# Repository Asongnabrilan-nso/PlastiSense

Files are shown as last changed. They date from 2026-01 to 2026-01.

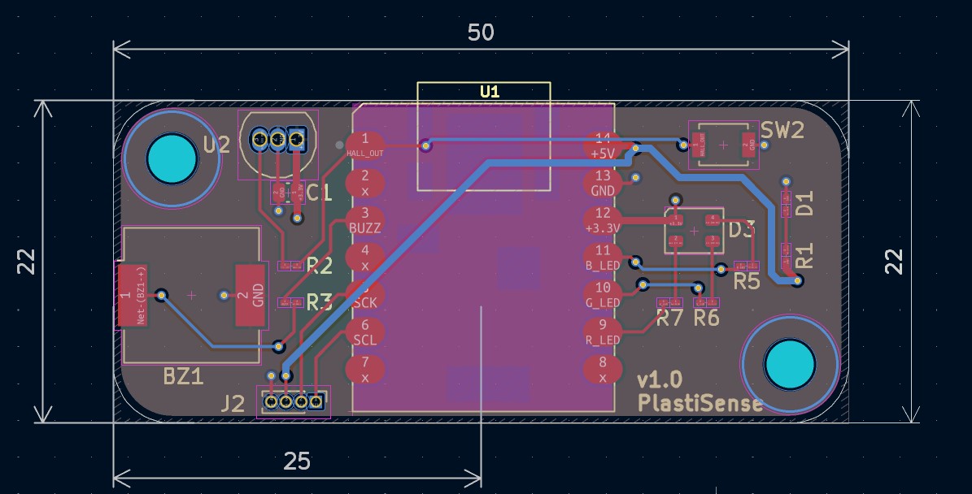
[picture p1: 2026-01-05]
Hardware/PCB Caption.jpg

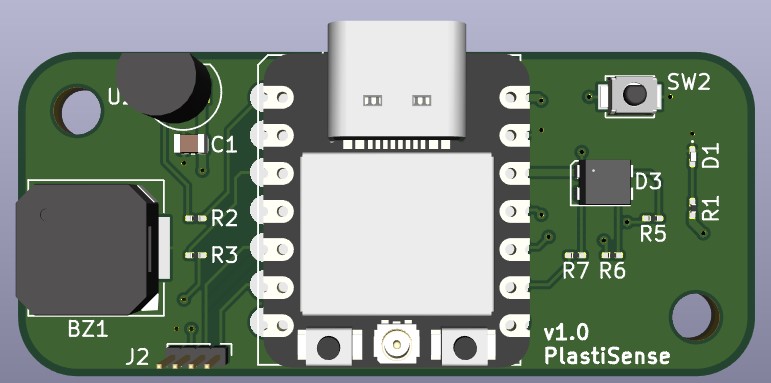
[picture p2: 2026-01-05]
Hardware/PCB-3D.jpg

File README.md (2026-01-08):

[Video: PlastiSense Demo](https://youtu.be/B_dy0DAJdtQ)

# PlastiSense

PlastiSense is a precise **filament diameter sensor** powered by the **Seeed Studio XIAO ESP32-C3**. It is designed to monitor filament quality in real-time, offering a web-based dashboard and API for data integration.

## 🚀 Features

-   **Real-time Measurement**: High-precision diameter readings in millimeters (mm).
-   **Web Dashboard**: Hosted on the device itself (`http://winfidel.local`), providing a visual interface for monitoring.
-   **REST API**: JSON endpoints for easy integration with other systems (e.g., OctoPrint, Home Assistant).
-   **WiFi Connectivity**: Connects to your home/office network.
-   **Captive Portal**: Easy initial setup via the `SK-WInFiDEL-Setup` access point.
-   **OTA Updates**: Support for Over-The-Air firmware updates.

## 🛠️ Hardware

The project is built around:
-   **Microcontroller**: [Seeed Studio XIAO ESP32-C3](https://www.seeedstudio.com/Seeed-XIAO-ESP32C3-p-5431.html)
-   **Custom PCB**: Files located in the `PlastiSense_PCB` dictionary.
-   **Stl Files**: 3D printable case files located in `stl` directory.

## 📁 Project Structure

-   `Firmware/`: Source code for the ESP32-C3 firmware (PlatformIO project).
-   `Hardware/`: Mechanical parts and diagrams.
-   `PlastiSense_PCB/`: KiCad PCB design files.
-   `stl/`: 3D printable STL files for the sensing unit.

## ⚡ Getting Started

### 1. Build & Flush Firmware
Detailed instructions for building and flashing the firmware can be found in the [Firmware Documentation](Firmware/README.md).

### 2. Connect to the Device
1.  Power on the PlastiSense device.
2.  Connect to the WiFi network named **SK-WInFiDEL-Setup**.
3.  A captive portal should open. If not, visit `http://192.168.4.1`.
4.  Configure your local WiFi credentials.

### 3. Access the Dashboard
Once connected to your network, access the device at:
-   **URL**: `http://winfidel.local`
-   **API Endpoint**: `http://winfidel.local/api/v0/diameter/read`

For more details on connection and API usage, see the [Connection Guide](Firmware/connection.md).

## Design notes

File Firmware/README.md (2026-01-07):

# How to build firmware

For our firmware development, we are going to use Arduino. Mainly because it's user friendly, easy to use and
most hobbyists are familiar with it or have already used it. While we could build the same or even more efficient
firmware using bare-metal C and ESP-IDF, we are going to stick with Arduino and hope that this allows the project to be
more friendly and easier to use/modify by wider DIY/hacker community.

## How can I build/compile firmware?

### 1. Install PlatformIO
Installing PlatformIO CLI is pretty straight-forward and also well documented for Windows, Linux and MacOS.
You will need to follow few steps and get PlatformIO CLI installed, detailed tutorial can be found at https://platformio.org/install/cli
Make sure to install [PlatformIO Core](https://docs.platformio.org/en/latest//core/installation.html#installation-methods 'https://docs.platformio.org/en/latest//core/installation.html#installation-methods') and allso that it is available trough [shell](https://docs.platformio.org/en/latest//core/installation.html#piocore-install-shell-commands 'PlatformIO Core - Install Shell Commands¶').

### 2. Build firmware
Open shell/command-prompt and navigate to 'Firmware/platformio' folder.

1. Compile and upload the firmware with `pio run --target upload --upload-port <COM-PORT>`. Make sure to replace `<COM-PORT>` with your ESP32's COM port (ie COM1 or /dev/ttyACM0)
2. Upload the file system (Web page) with `pio run --target uploadfs --upload-port <COM-PORT>`, again replace `<COM-PORT>` with your ESP32's COM port.
3. Restart/power-cycle your board

Every time you make a firmware change, you need to run step #1.
Every time you make a change to the web page (anything inside `data` folder) you only need to run step #2.

[<- Go back to repository root](../README.md)

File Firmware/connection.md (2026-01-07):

Connecting to WInFiDEL ("Log In" Process)
There is no traditional "Log In" screen for the web interface itself. The security is handled by the WiFi connection.

Step 1: Initial Setup (The "Login")
When the device is fresh or reset, it creates its own WiFi network. This is where you "log in" by providing your home WiFi credentials.

Power on your XIAO ESP32-C3 device.
On your phone or computer, look for a WiFi network named SK-WInFiDEL-Setup.
Connect to this network.
A page should pop up automatically ("Captive Portal").
If it doesn't pop up, open a browser and go to http://192.168.4.1
Click Configure WiFi.
Select your home/office WiFi network.
Enter your WiFi Password.
Click Save.
The device will now save these credentials, disconnect from your phone, and connect to your home network.

Step 2: Accessing the Interface
Once the device is connected to your home network, anyone on that network can access it.

Connect your phone/computer back to your Home WiFi.
Open a browser and go to:
http://winfidel.local
Note: If winfidel.local doesn't work (common on some Windows setups or Androids), you will need the device's IP address. You can find this in your router's device list, or by monitoring the Serial output (USB) when the device boots.
Step 3: Using the API
The API is open to anyone on the network. You do not need a username or password.

View Dashboard: http://winfidel.local/index.html
Settings: http://winfidel.local/settings.html
Raw Data (API): http://winfidel.local/api/v0/diameter/read
NOTE

If you messed up the WiFi password in Step 1, you can reset the settings via the Serial Monitor or by reflashing the device, and start over from Step 1.

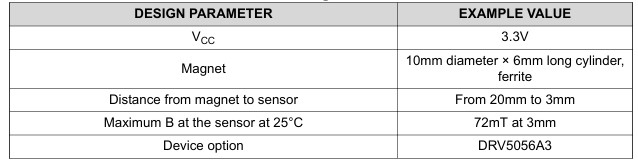
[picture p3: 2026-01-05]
assets/design parameter.jpg

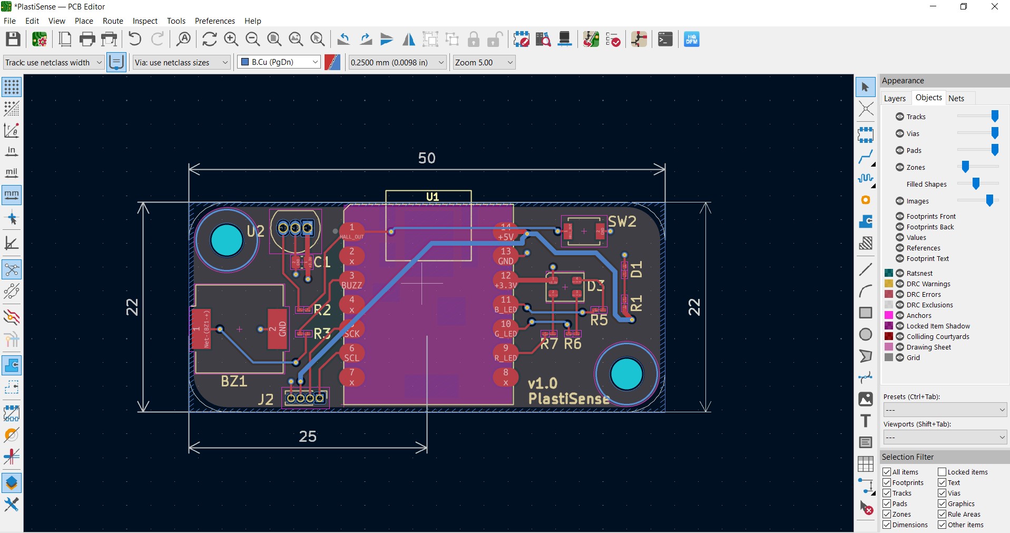
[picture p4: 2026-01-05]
Hardware/PCB-image.jpg

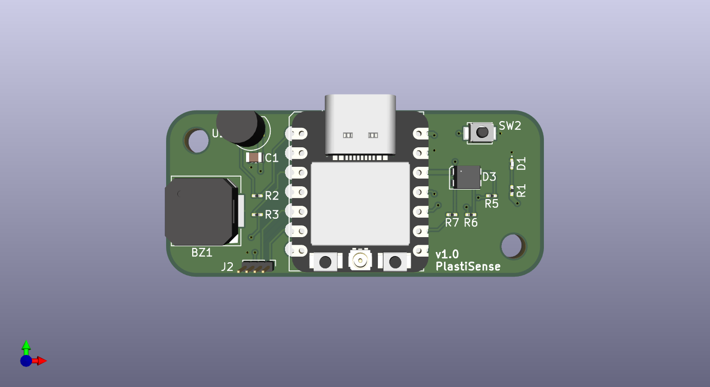
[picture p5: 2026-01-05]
Hardware/PlastiSense.png

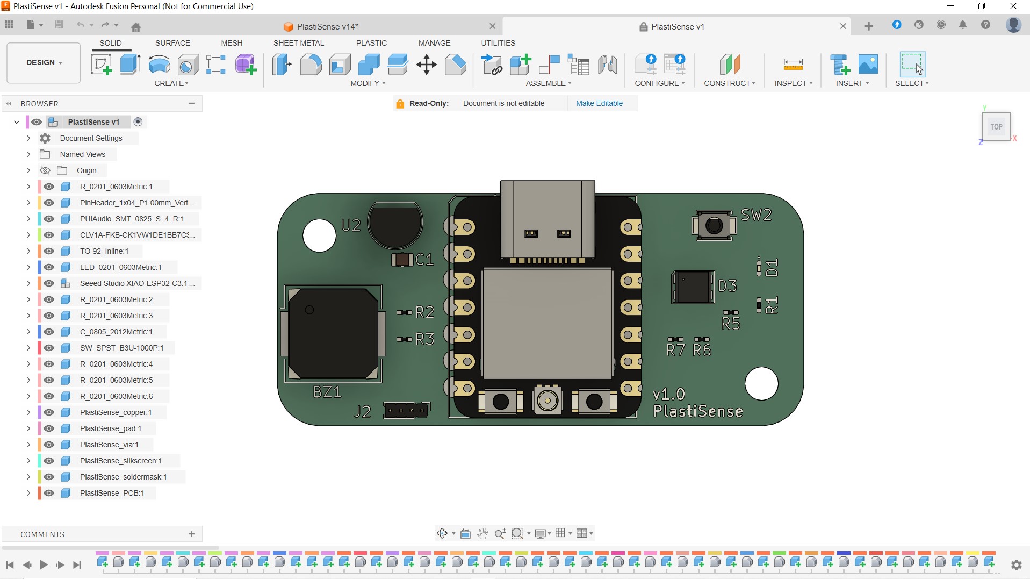
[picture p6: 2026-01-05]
Hardware/PCB-Fusion.jpg

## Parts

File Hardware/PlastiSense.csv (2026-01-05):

Reference | Qty | Value | DNP | Exclude from BOM | Exclude from Board | Footprint
BZ1 | 1 | Buzzer |  |  |  | Buzzer_Beeper:Buzzer_CUI_CPT-9019S-SMT
C1 | 1 | 0.1uF |  |  |  | Capacitor_SMD:C_0504_1310Metric_Pad0.83x1.28mm_HandSolder
D1 | 1 | GREEN |  |  |  | LED_SMD:LED_0201_0603Metric_Pad0.64x0.40mm_HandSolder
D3 | 1 | CLV1L-FKB |  |  |  | LED_SMD:LED_Cree-PLCC4_3.2x2.8mm_CCW
H1,H2 | 2 | MountingHole |  | Excluded from BOM |  | MountingHole:MountingHole_3.2mm_M3
J2 | 1 | Conn_01x04 |  |  |  | Connector_PinHeader_1.00mm:PinHeader_1x04_P1.00mm_Vertical
R1,R3 | 2 | 1k |  |  |  | Resistor_SMD:R_0201_0603Metric_Pad0.64x0.40mm_HandSolder
R2 | 1 | 4K7 |  |  |  | Resistor_SMD:R_0201_0603Metric_Pad0.64x0.40mm_HandSolder
R5,R6,R7 | 3 | 220 |  |  |  | Resistor_SMD:R_0201_0603Metric_Pad0.64x0.40mm_HandSolder
SW2 | 1 | SW_Push |  |  |  | Button_Switch_SMD:SW_SPST_B3U-1000P
U1 | 1 | MOUDLE-SEEEDUINO-XIAO-ESP32C3 |  |  |  | xiao ESP32C3_PCB:MOUDLE14P-SMD-2.54-21X17.8MM
U2 | 1 | HALL SENSOR |  |  |  | Package_TO_SOT_THT:TO-92_Inline

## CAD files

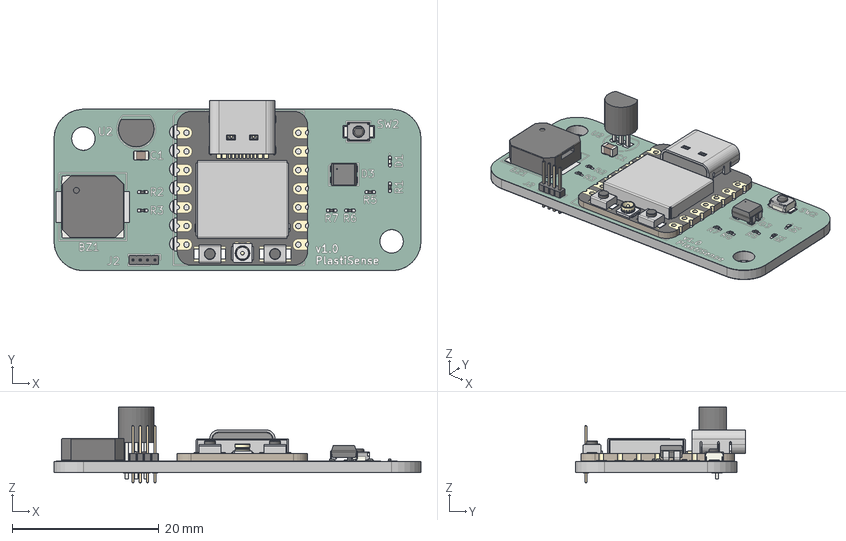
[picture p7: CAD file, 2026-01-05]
Hardware/PlastiSense.step
50.0 x 23.2 x 10.3 mm
R_0201_0603Metric x 6
PinHeader_1x04_P1.00mm_Vertical
PUIAudio_SMT_0825_S_4_R
CLV1A-FKB-CK1VW1DE1BB7C3C3_CRE
TO-92_Inline
LED_0201_0603Metric
BOSS-EXTRUDE14_8_
BOSS-EXTRUDE7_4_
BOSS-EXTRUDE7_3_
BOSS-EXTRUDE14_4_
BOSS-EXTRUDE14_2_
BOSS-EXTRUDE14_11_
BOSS-EXTRUDE7_7_
BOSS-EXTRUDE14_9_
BOSS-EXTRUDE14_3_
BOSS-EXTRUDE14_7_
MIRROR2
BOSS-EXTRUDE14_5_
BOSS-EXTRUDE14_12_
BOSS-EXTRUDE7_8_
BOSS-EXTRUDE7_1_
BOSS-EXTRUDE14_10_
BOSS-EXTRUDE7_9_
BOSS-EXTRUDE14_6_
BOSS-EXTRUDE14_1_
BOSS-EXTRUDE7_6_
BOSS-EXTRUDE7_2_
CUT-EXTRUDE5
BOSS-EXTRUDE7_5_
U.FL Connector v1
Button (1) x 2
Shield
C_0805_2012Metric
SW_SPST_B3U-1000P
PlastiSense_copper
PlastiSense_pad
PlastiSense_via
PlastiSense_silkscreen
PlastiSense_soldermask
PlastiSense_PCB

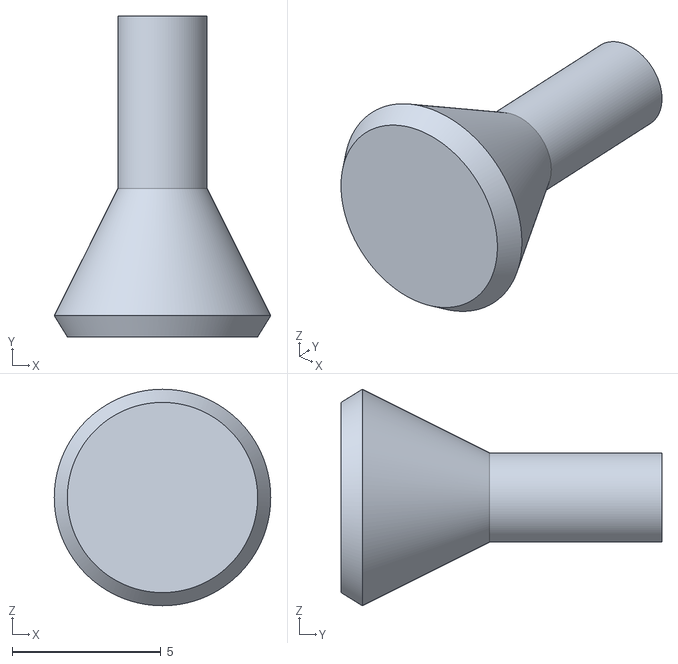
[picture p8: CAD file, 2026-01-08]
stl/BLOCKSTAND.stl
7.28 x 10.8 x 7.28

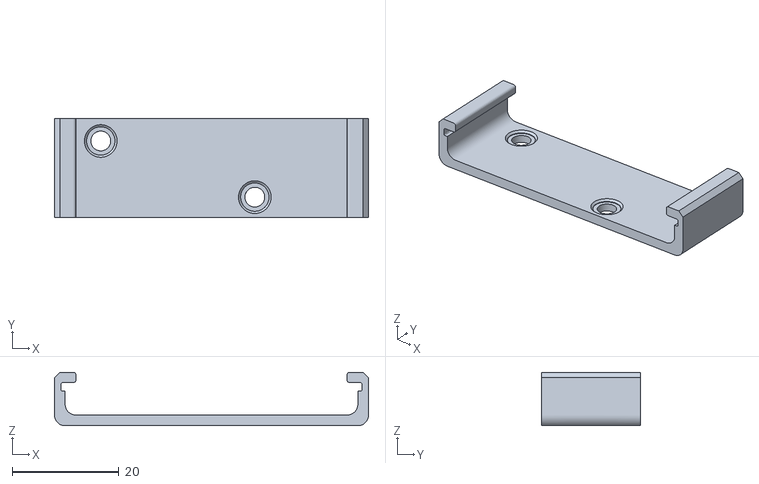
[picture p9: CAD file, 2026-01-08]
stl/ElectronicCase.stl
58.7 x 18.5 x 10.0

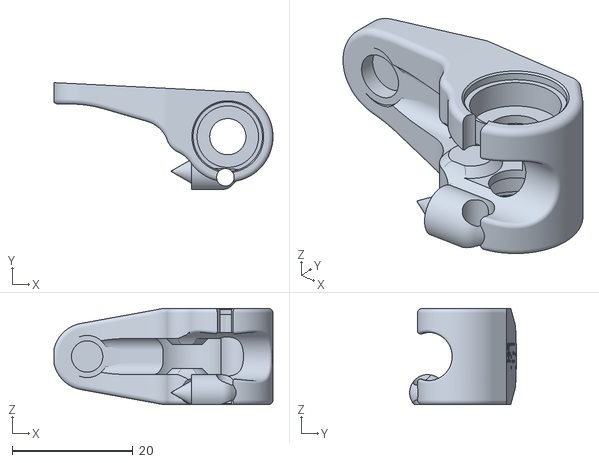
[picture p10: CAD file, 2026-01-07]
stl/PlastiSenseLever.stl
36.3 x 17.7 x 16.0

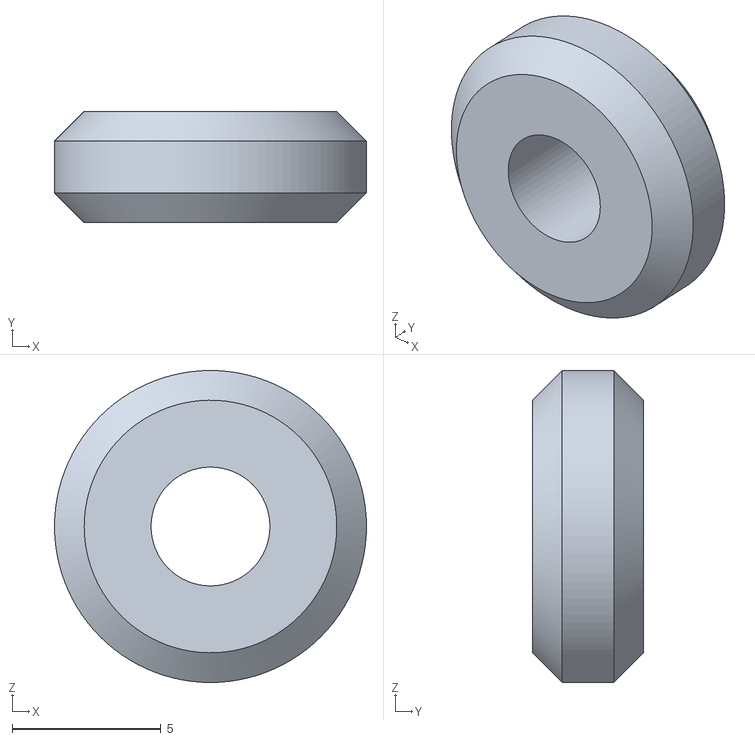
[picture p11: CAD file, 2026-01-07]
stl/Roller2.stl
10.5 x 3.75 x 10.5

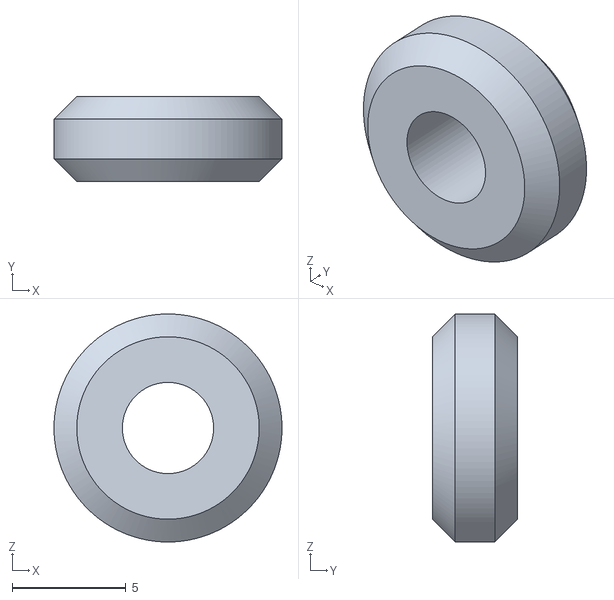
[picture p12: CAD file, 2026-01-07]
stl/Roller-1.stl
10.0 x 3.75 x 10.0

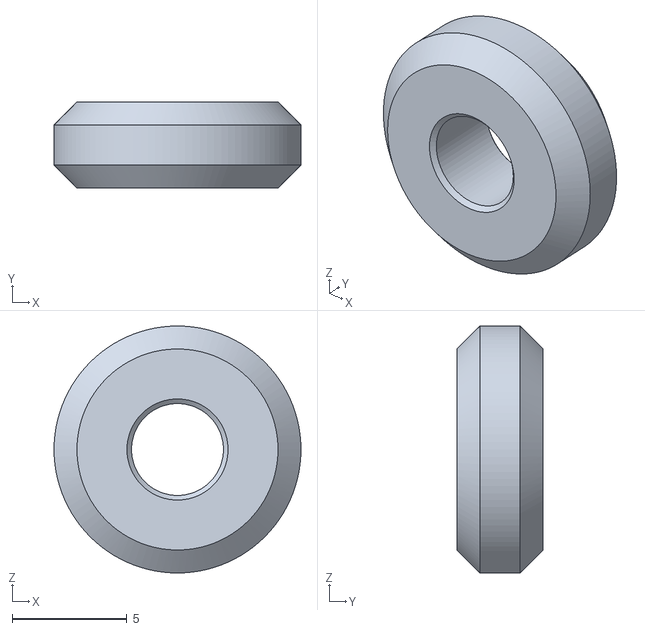
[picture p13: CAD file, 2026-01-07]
stl/Roller.stl
10.8 x 3.75 x 10.8

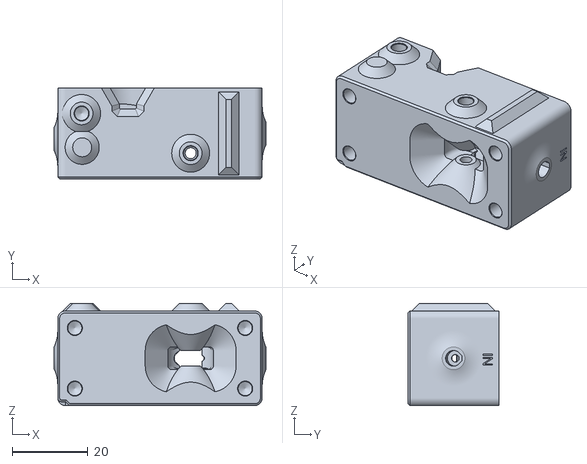
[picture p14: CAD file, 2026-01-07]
stl/PlastiSenseBlock.stl
56.0 x 24.0 x 27.0

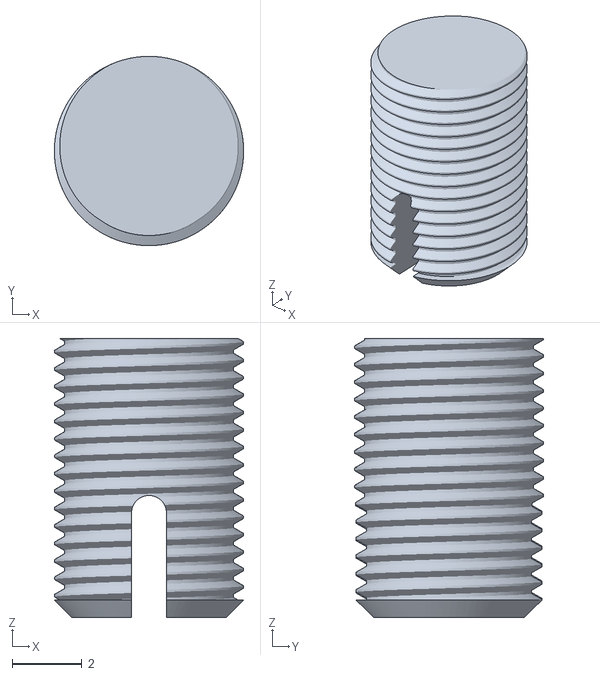
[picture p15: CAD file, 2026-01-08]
assets/Screw.stl
5.43 x 5.43 x 8.00

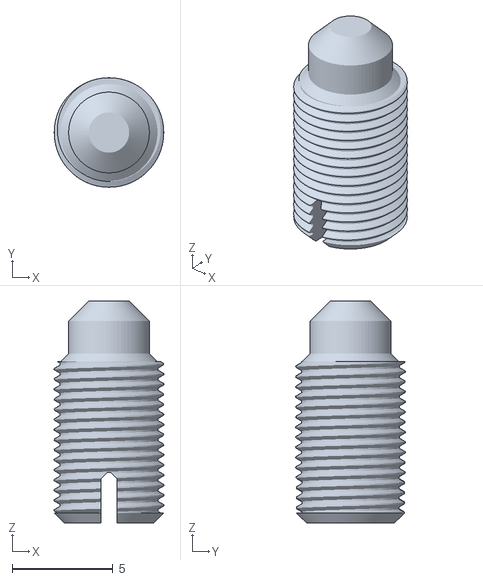
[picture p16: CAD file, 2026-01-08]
stl/Screw.stl
5.43 x 5.43 x 11.0

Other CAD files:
assets/Screw.f3d
stl/Screw.f3d

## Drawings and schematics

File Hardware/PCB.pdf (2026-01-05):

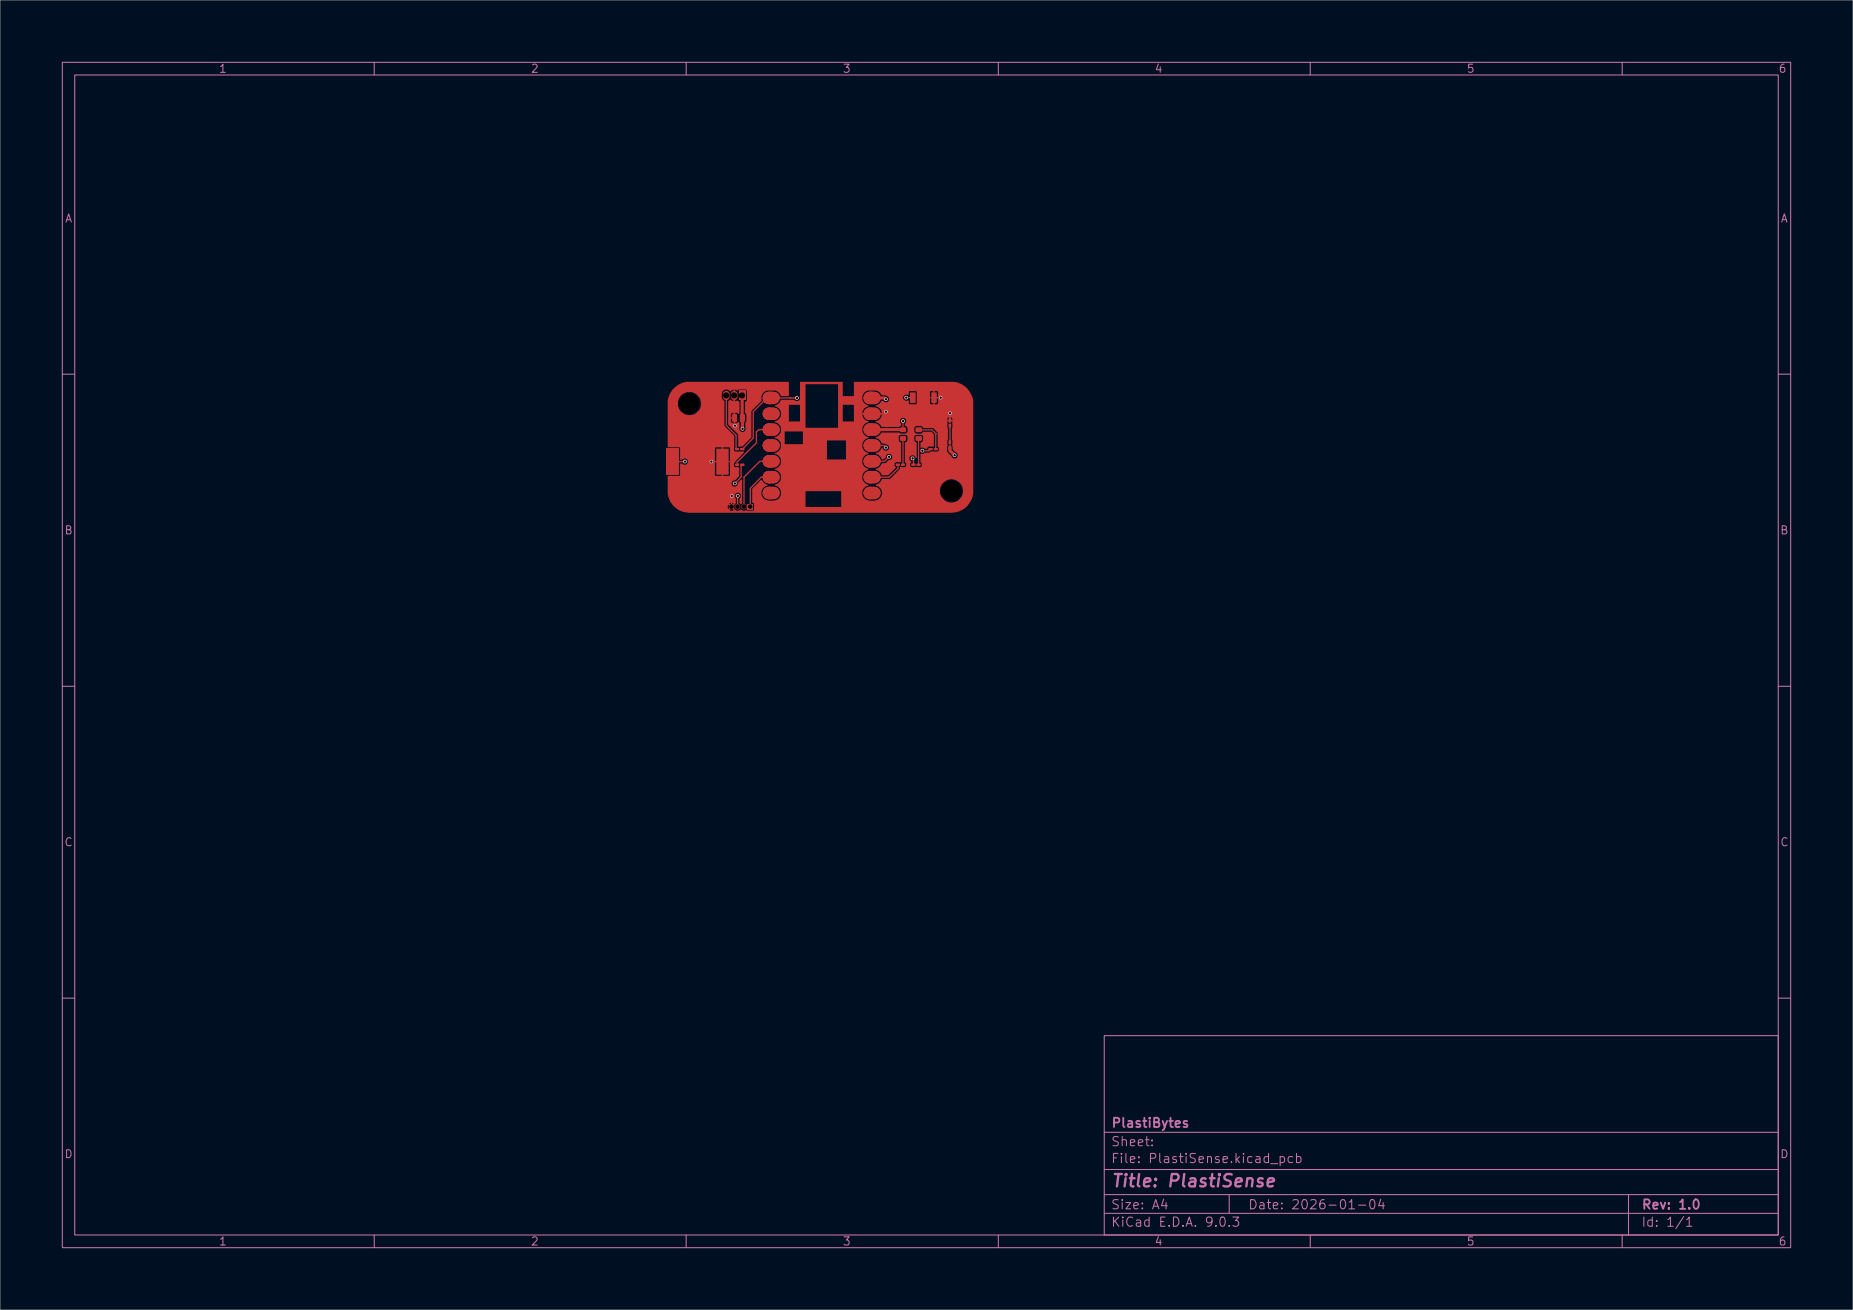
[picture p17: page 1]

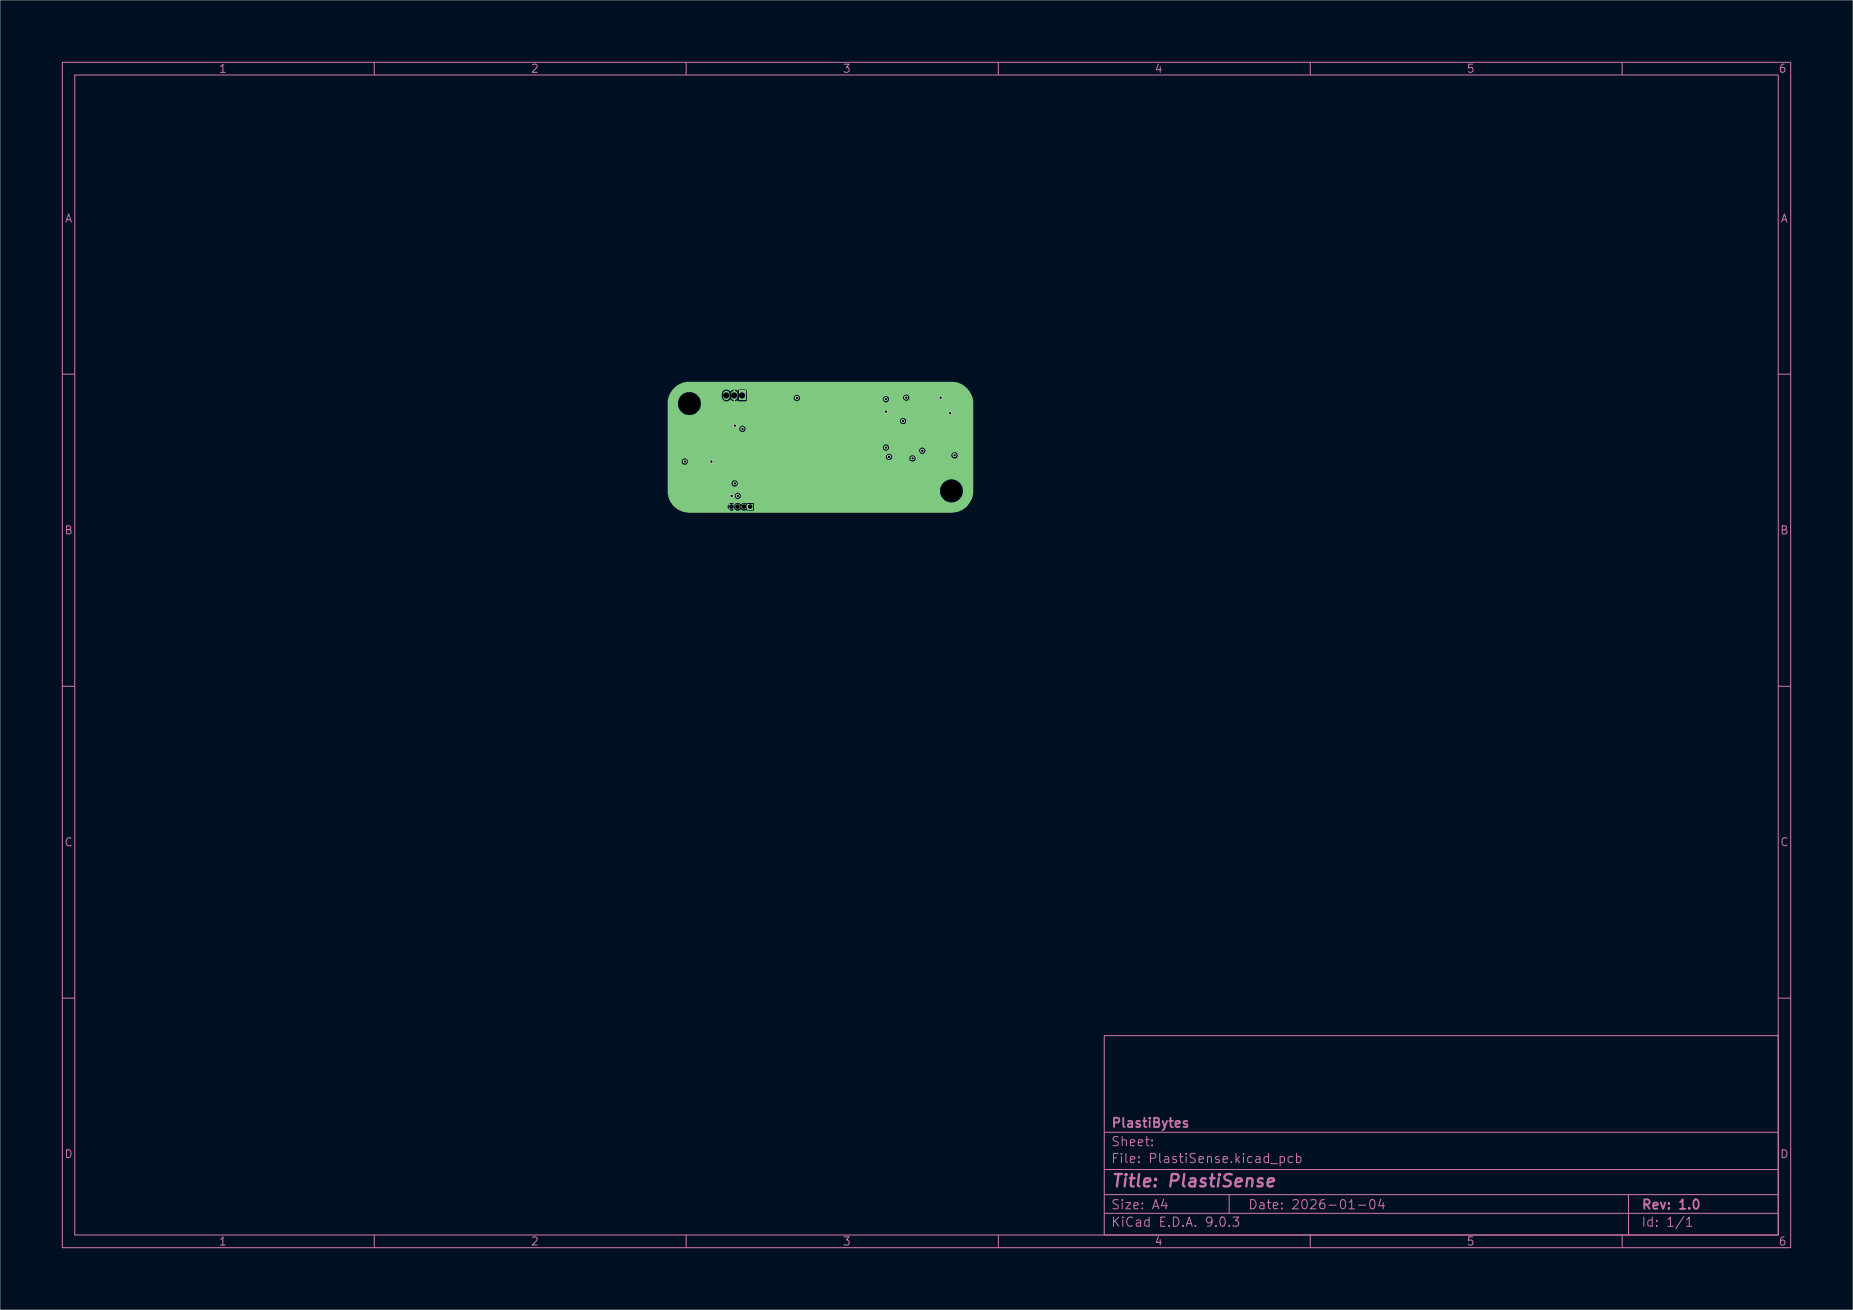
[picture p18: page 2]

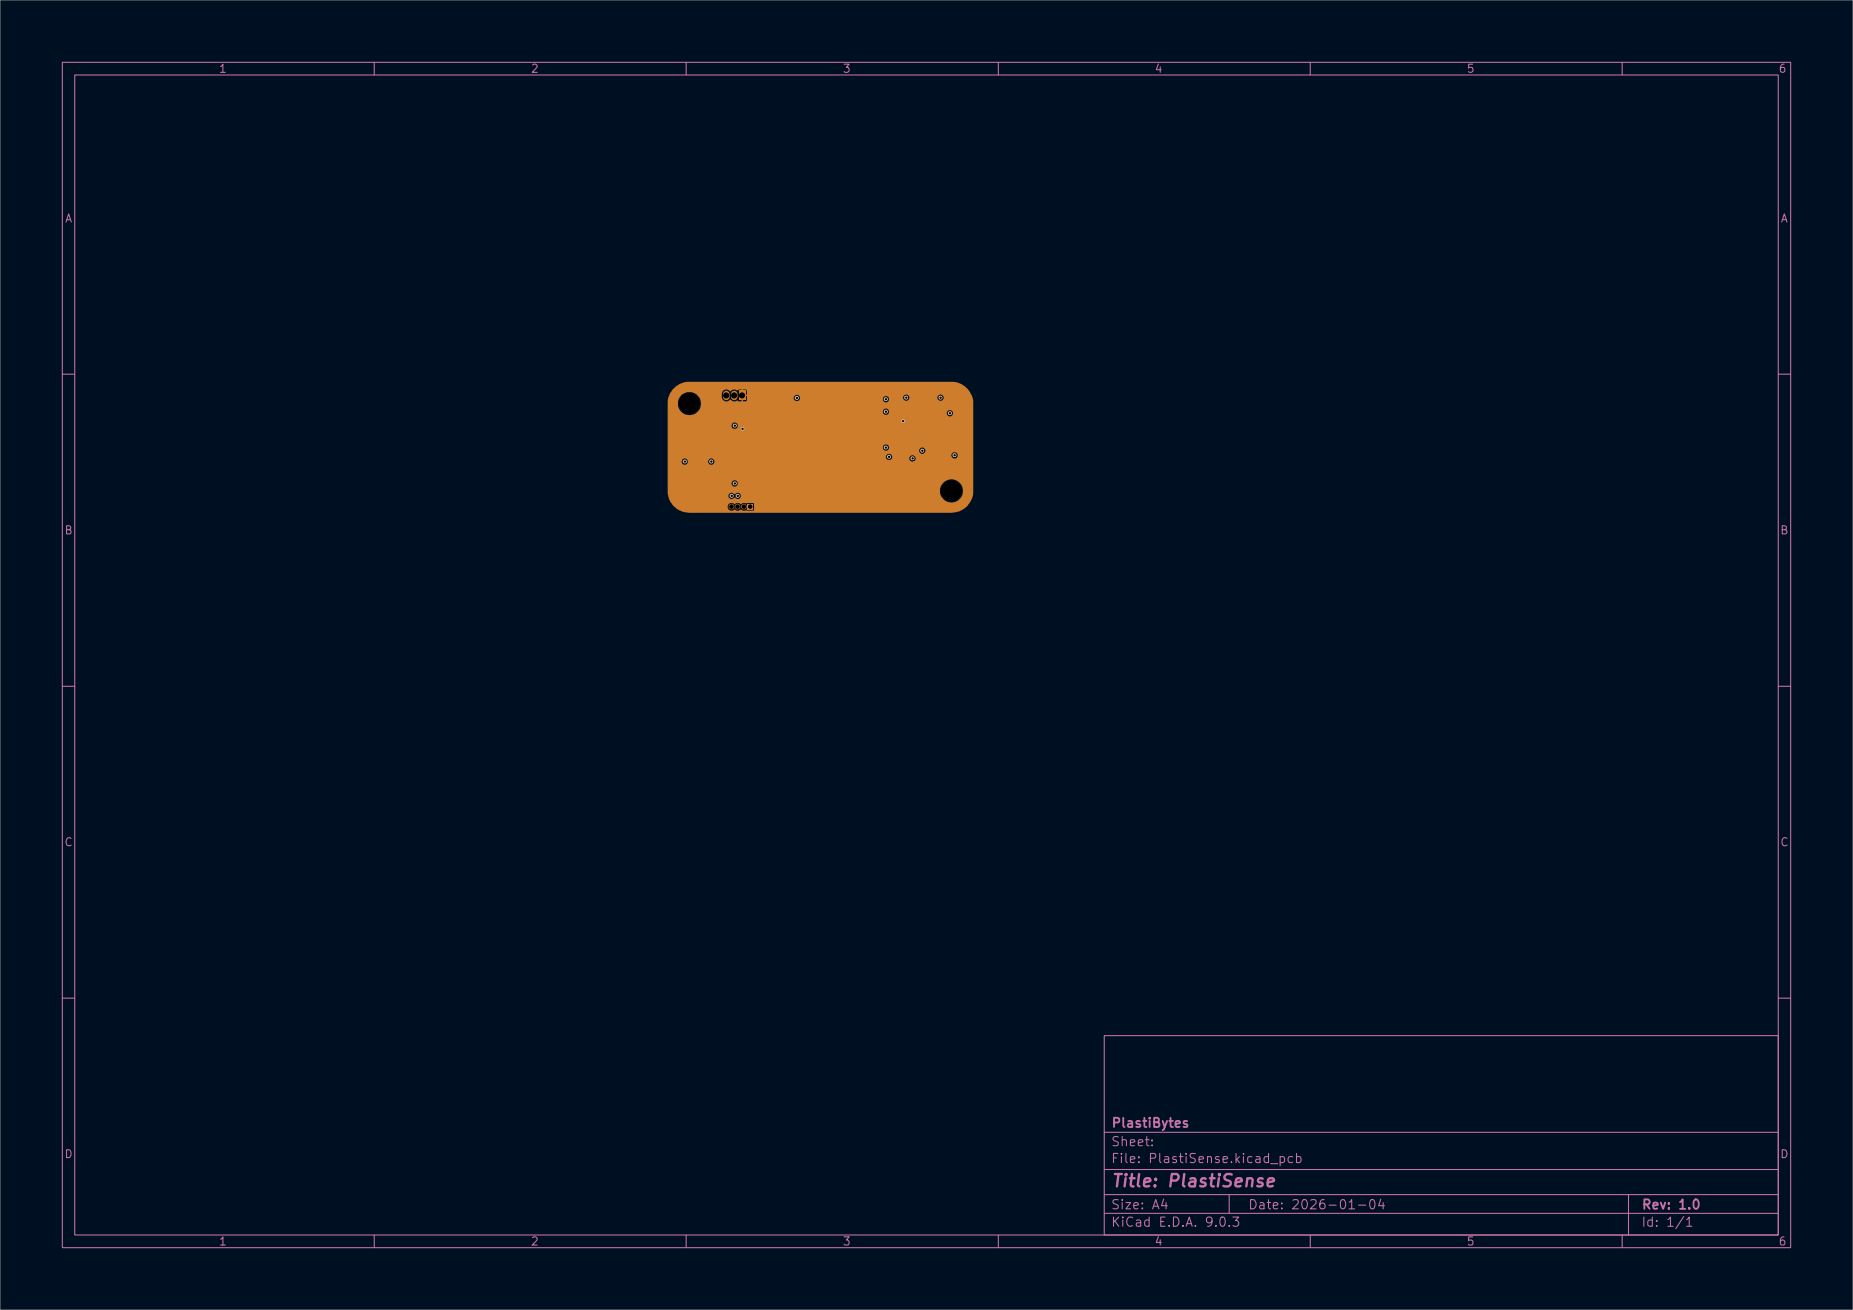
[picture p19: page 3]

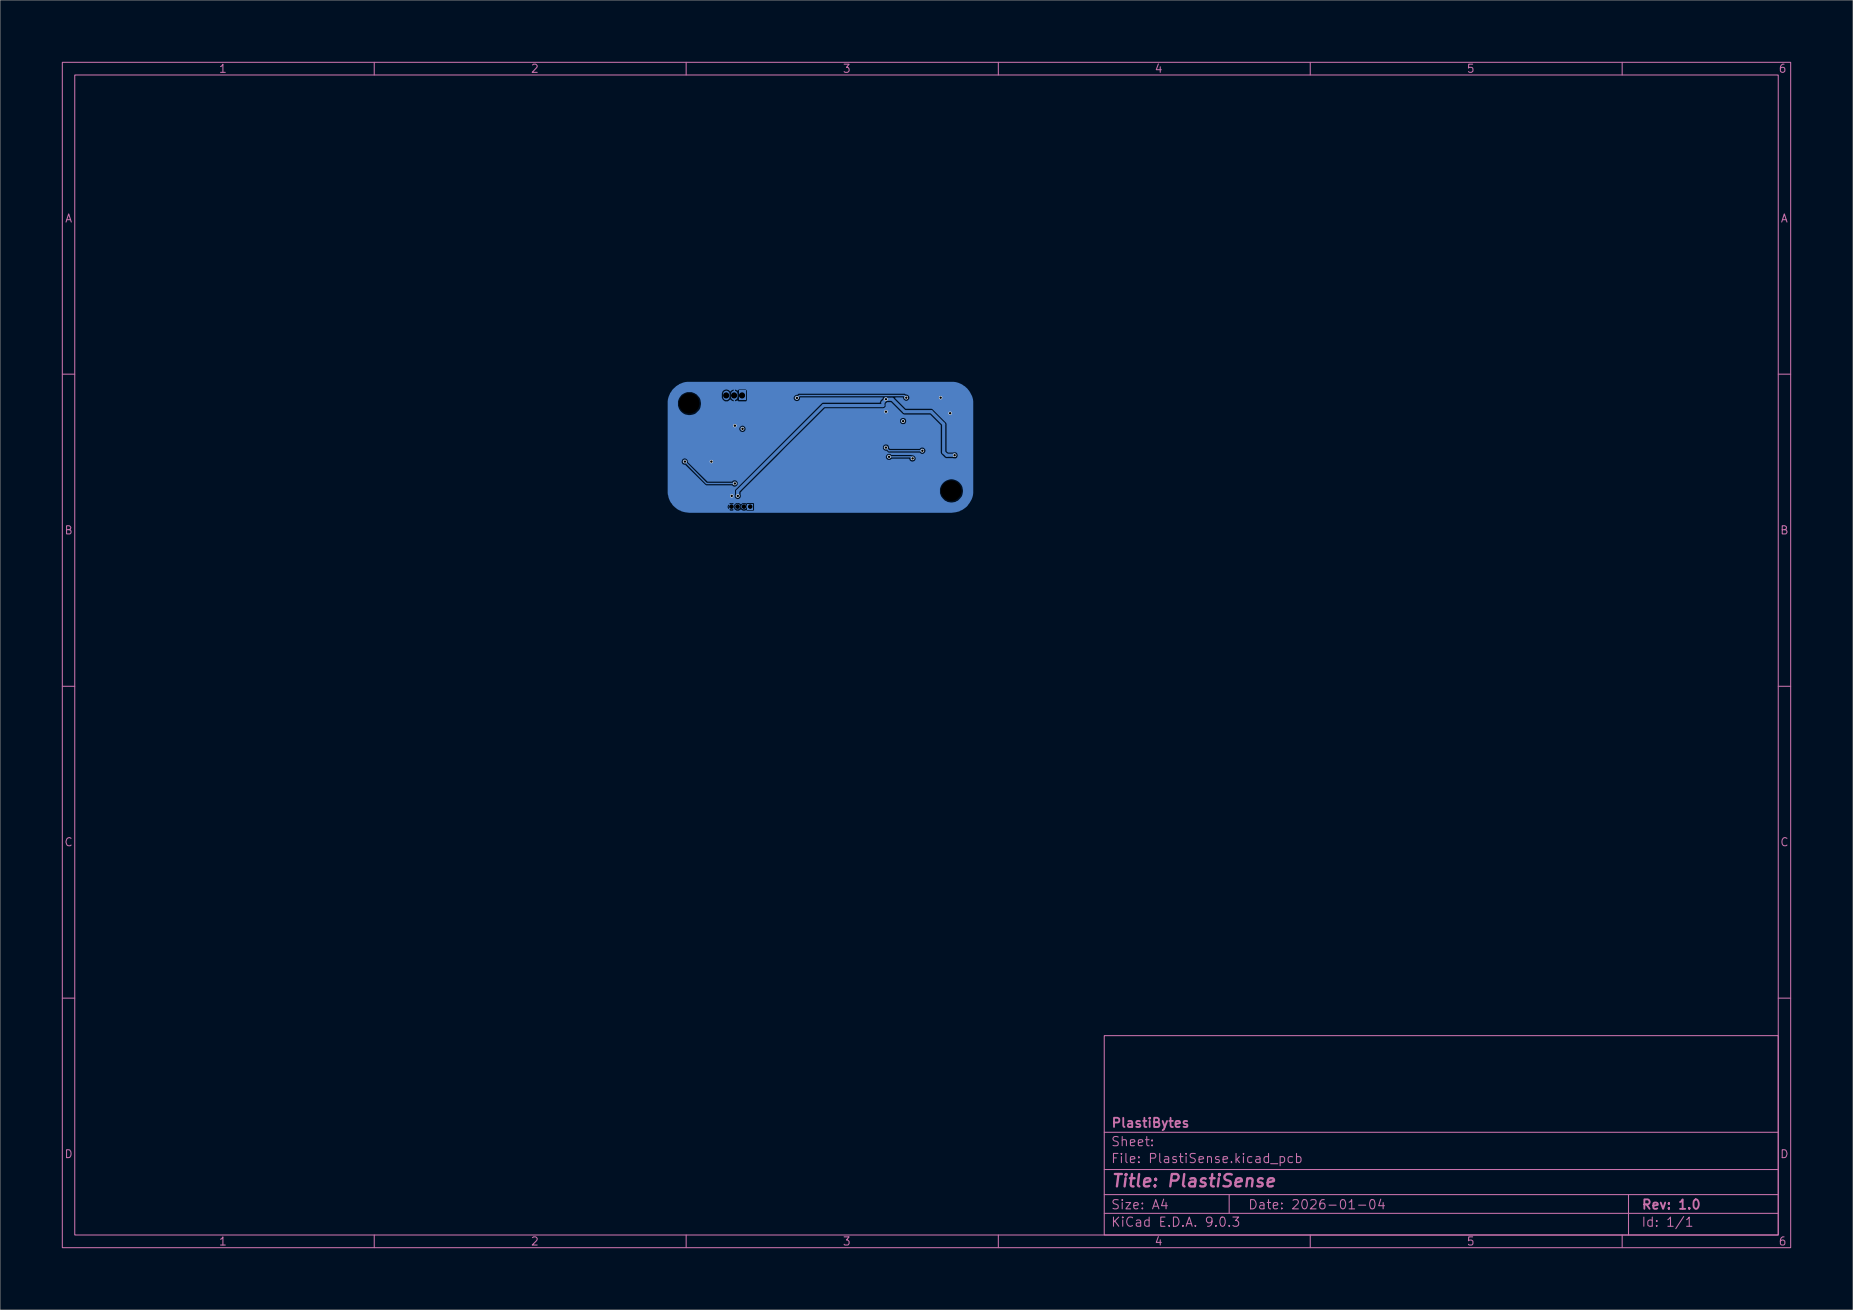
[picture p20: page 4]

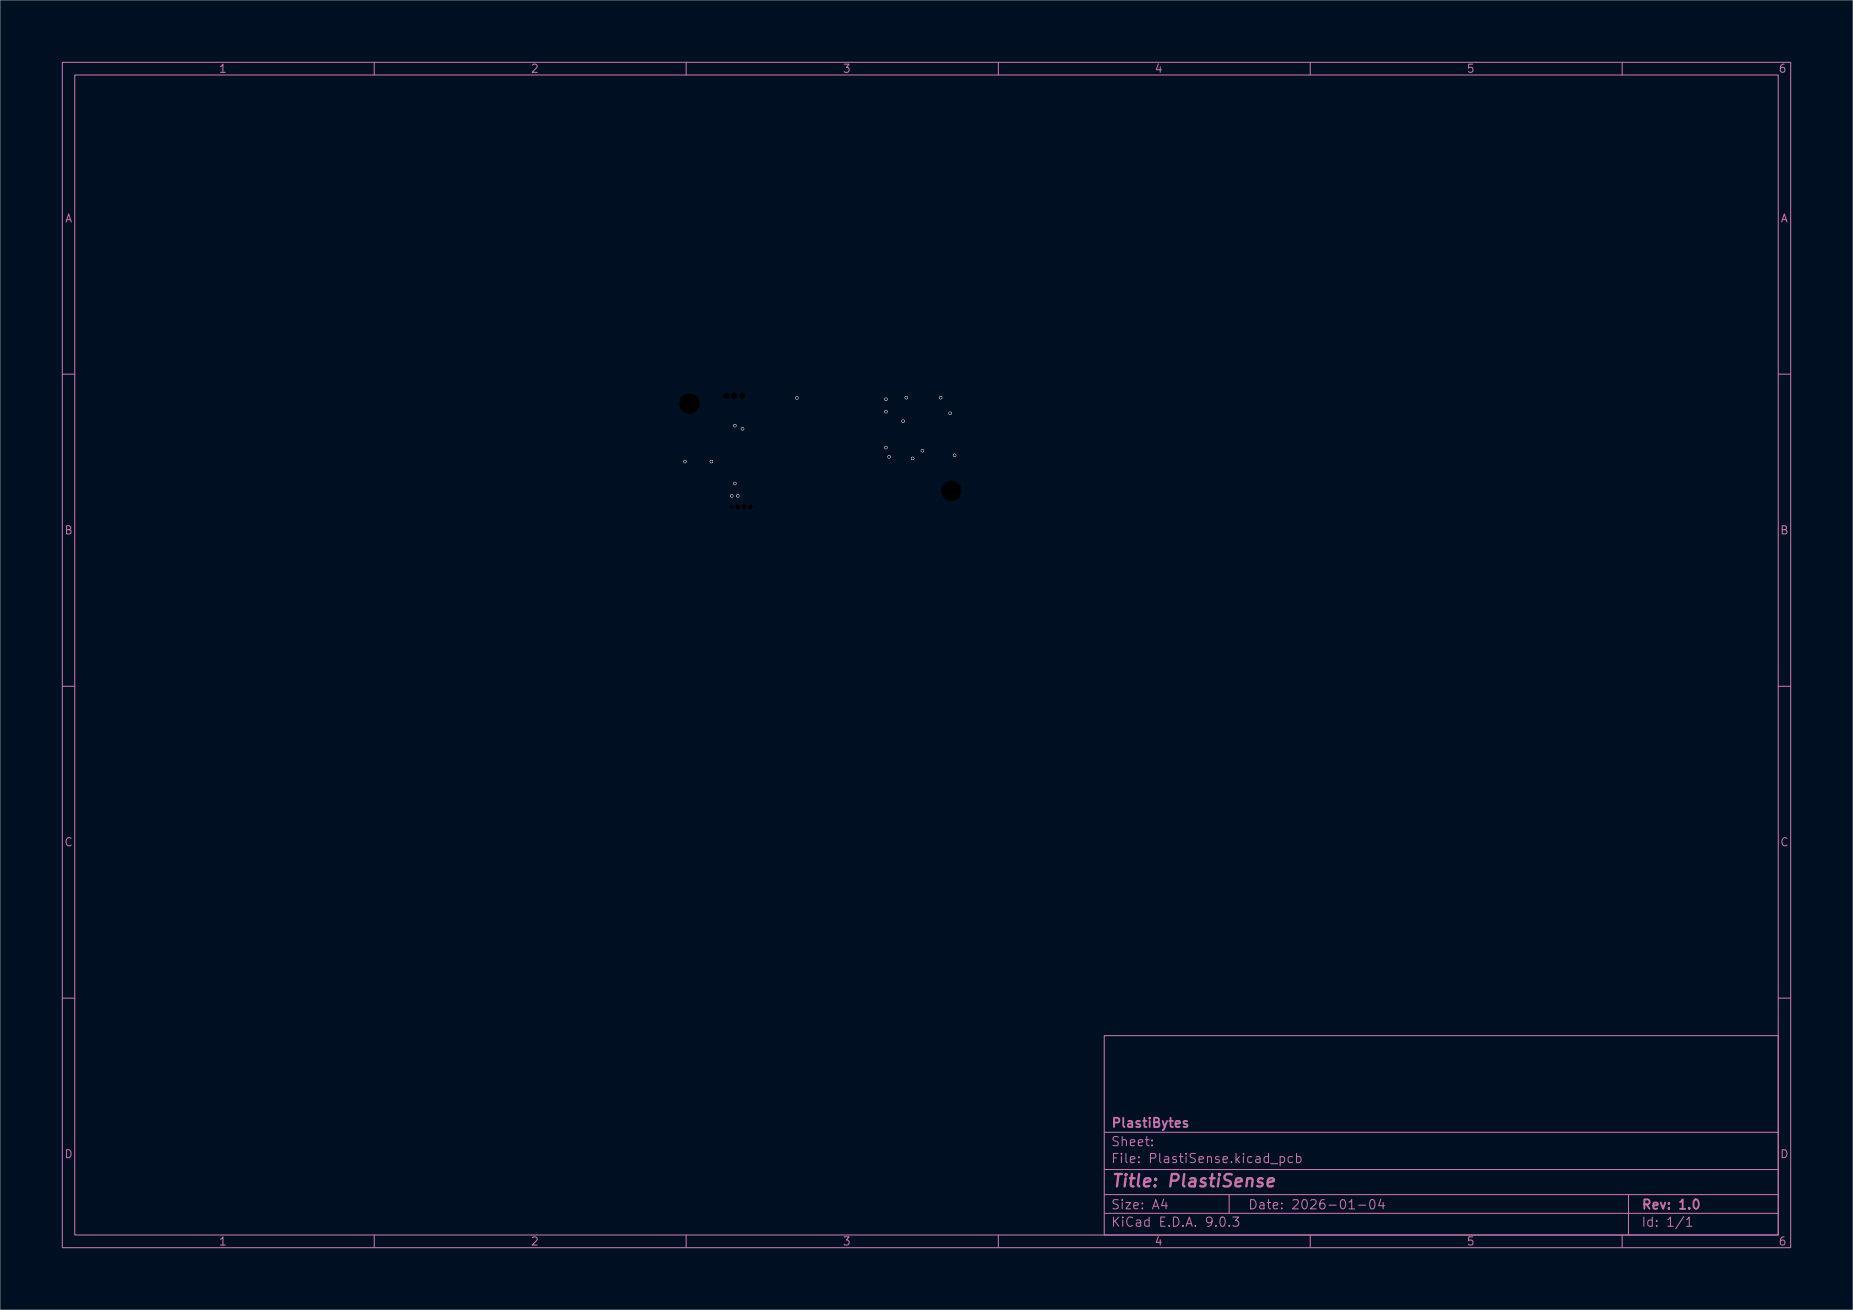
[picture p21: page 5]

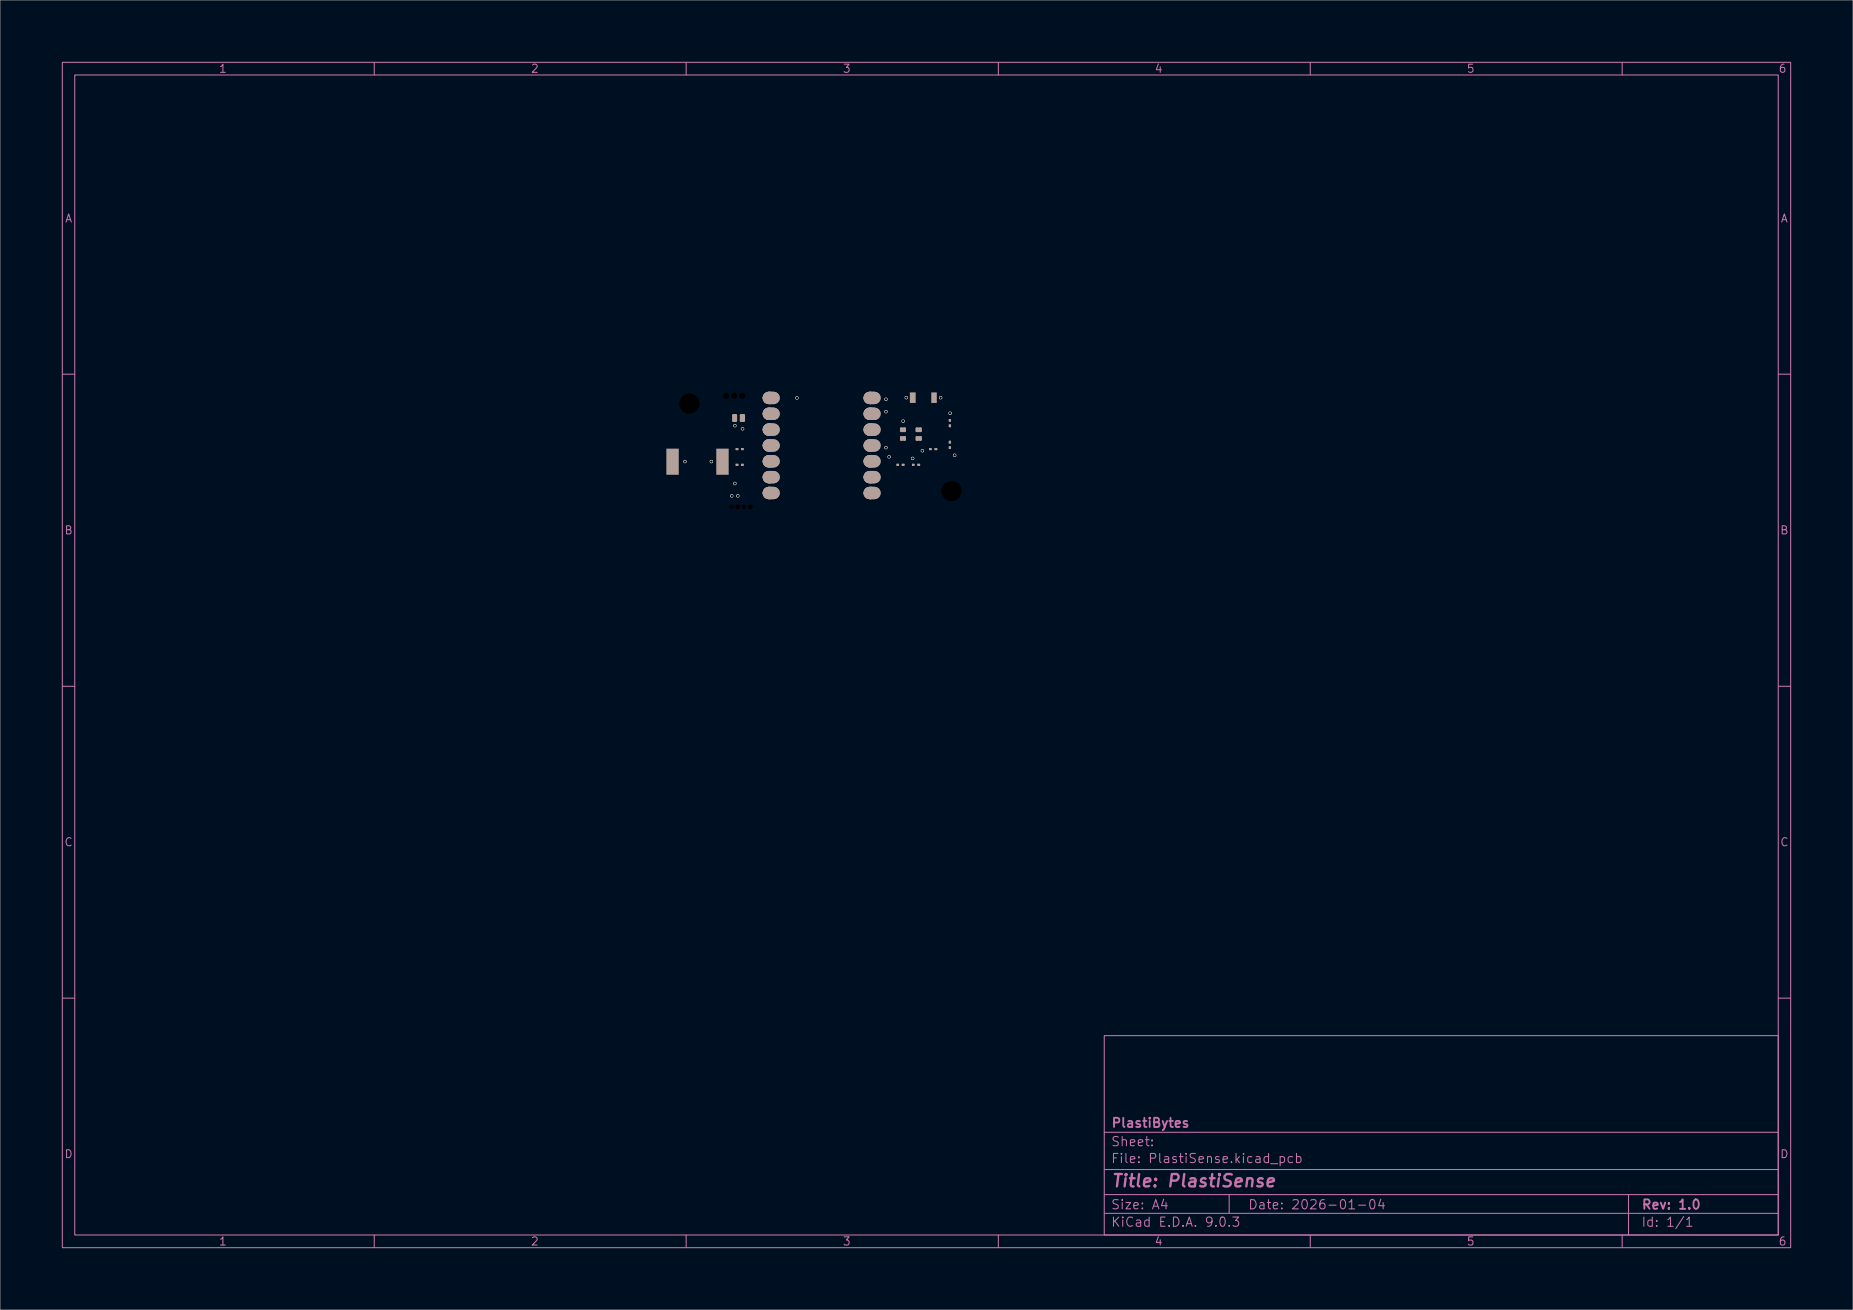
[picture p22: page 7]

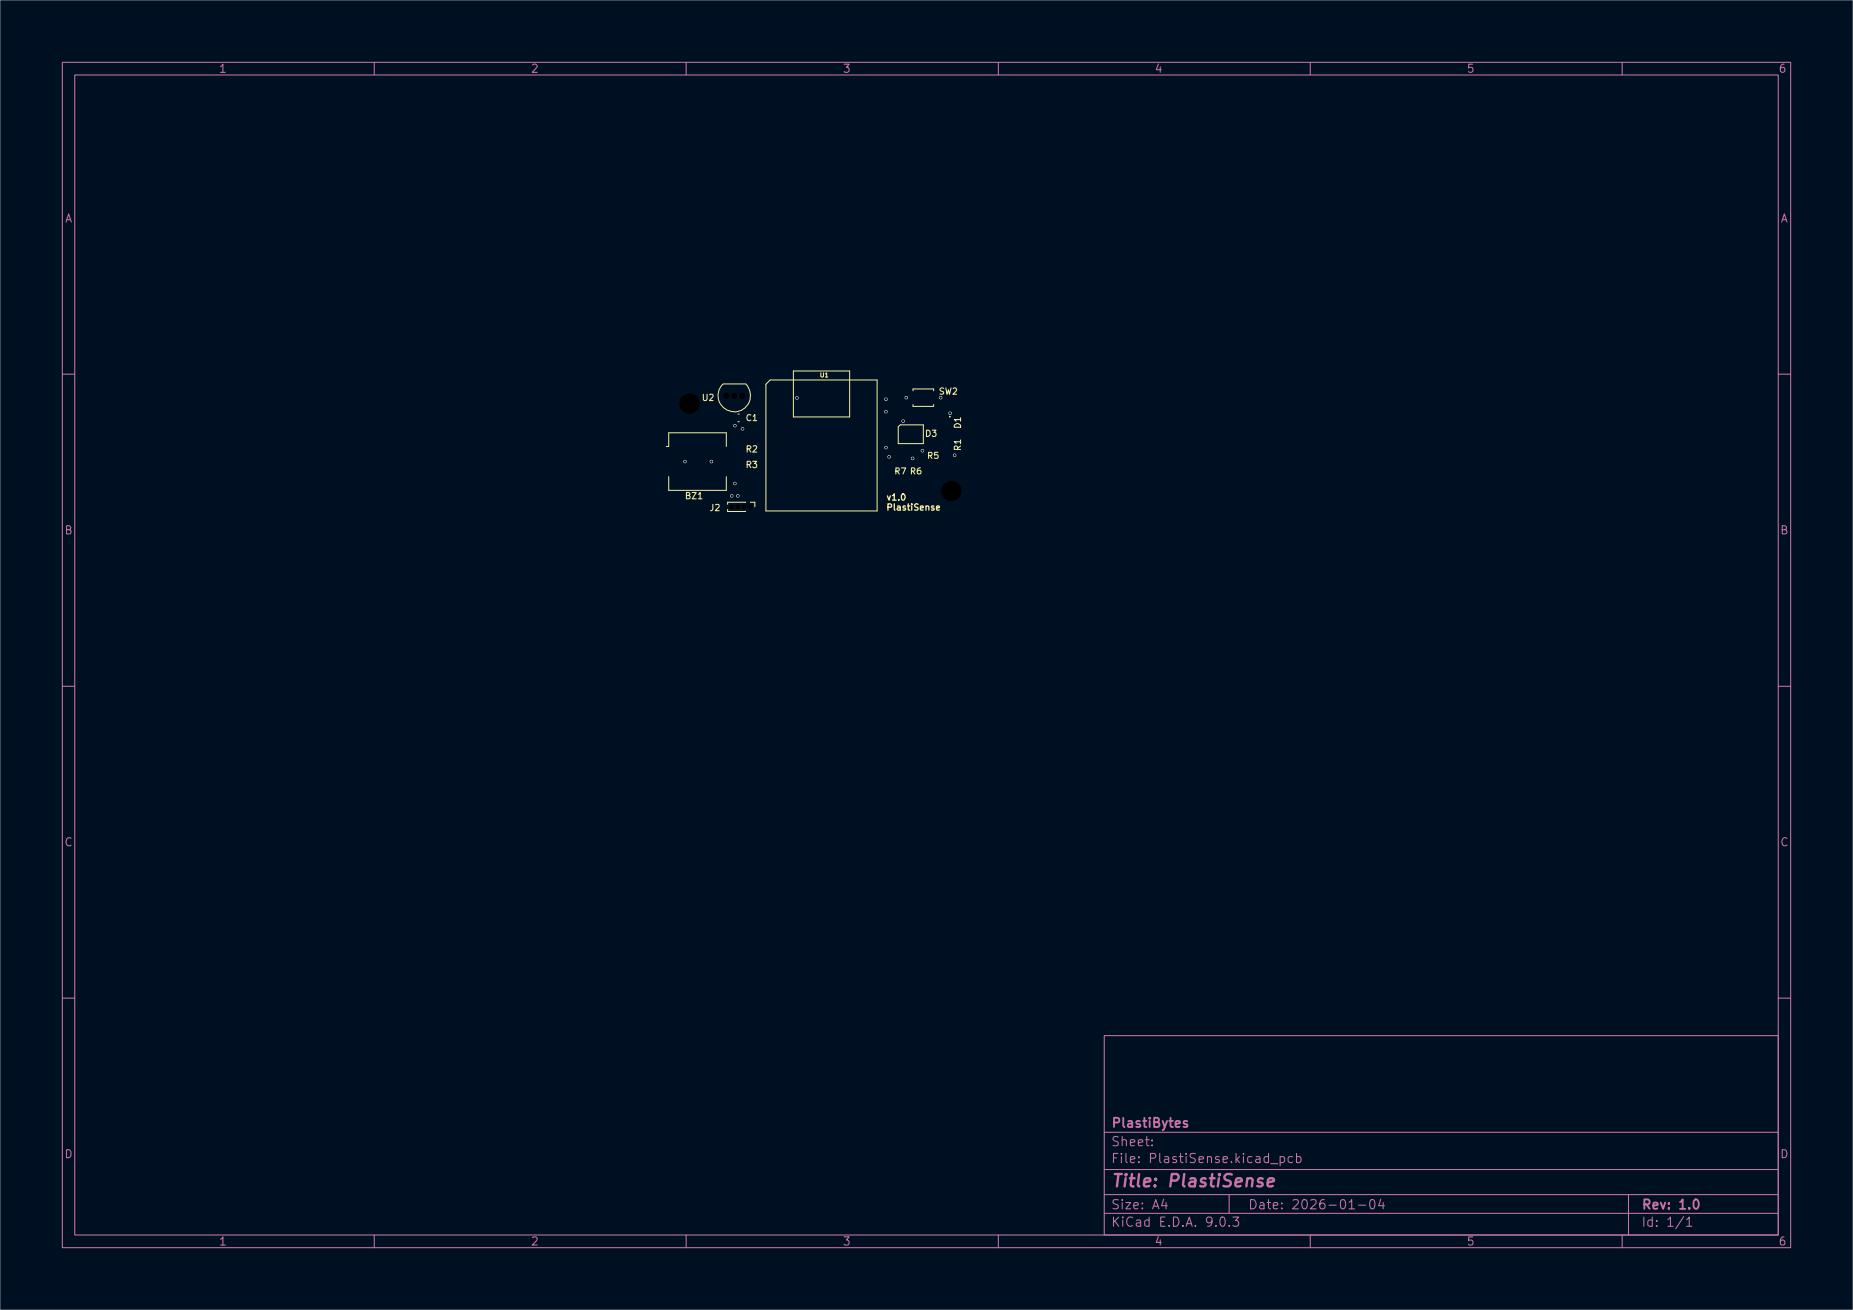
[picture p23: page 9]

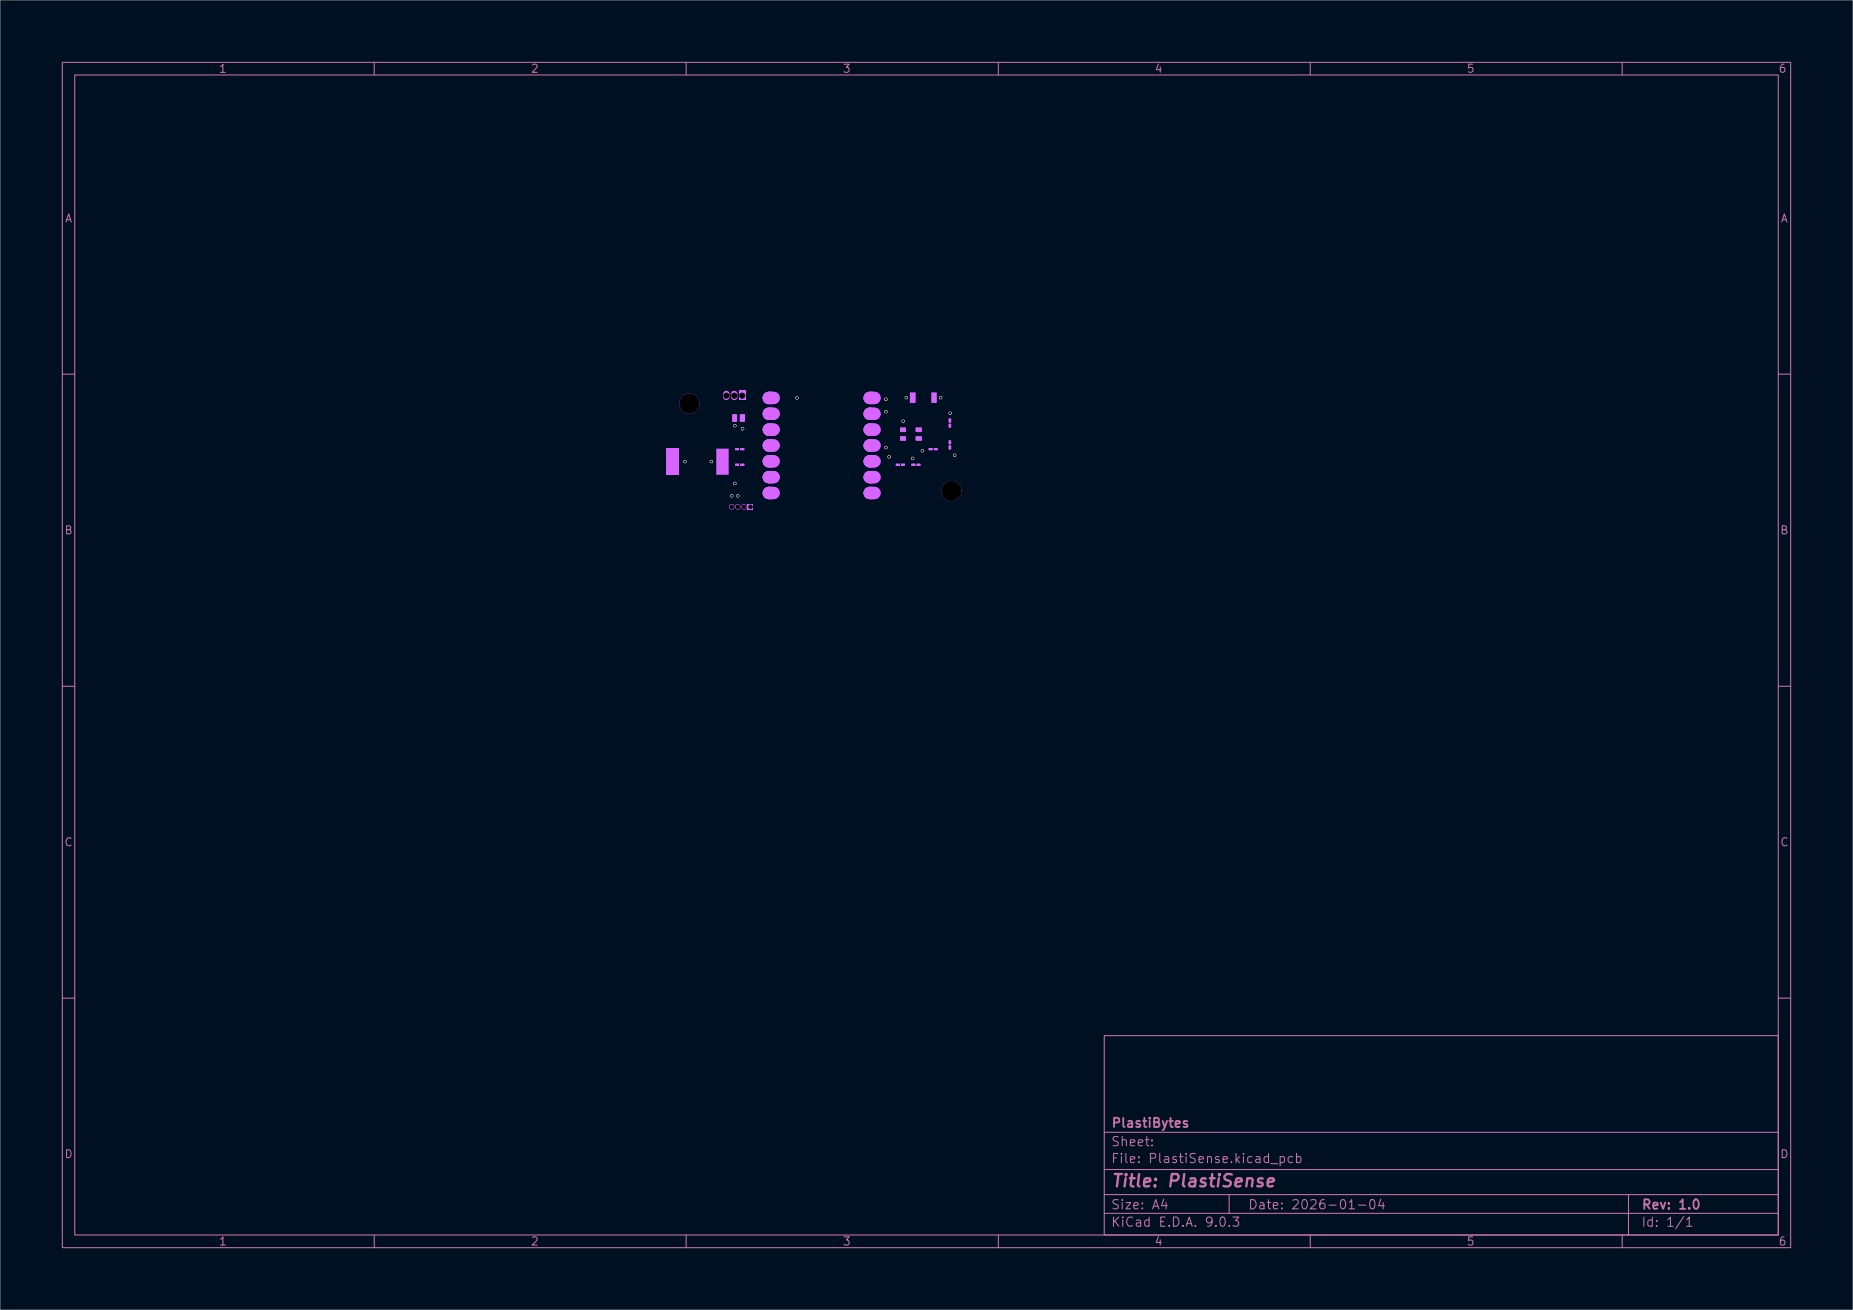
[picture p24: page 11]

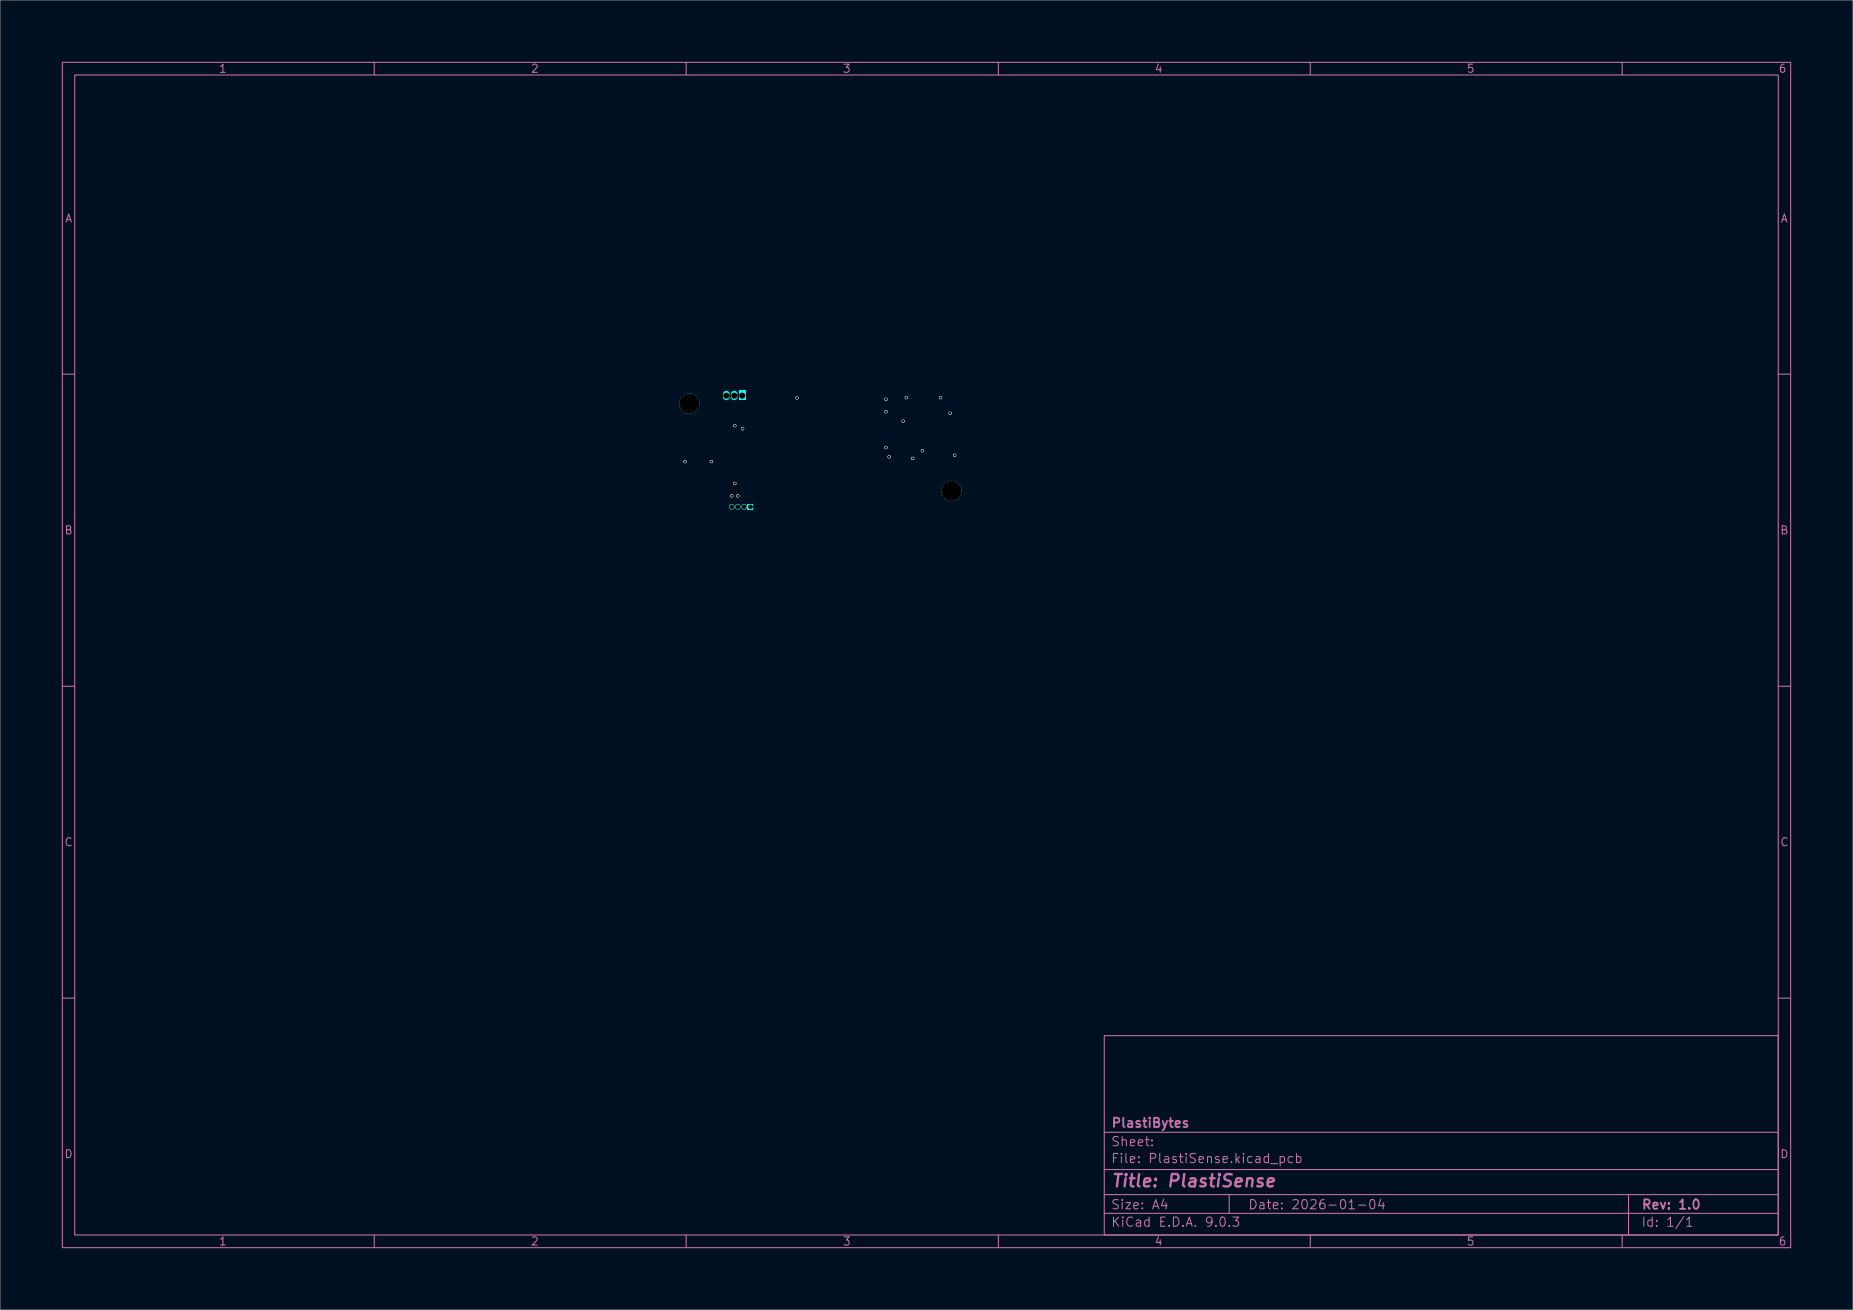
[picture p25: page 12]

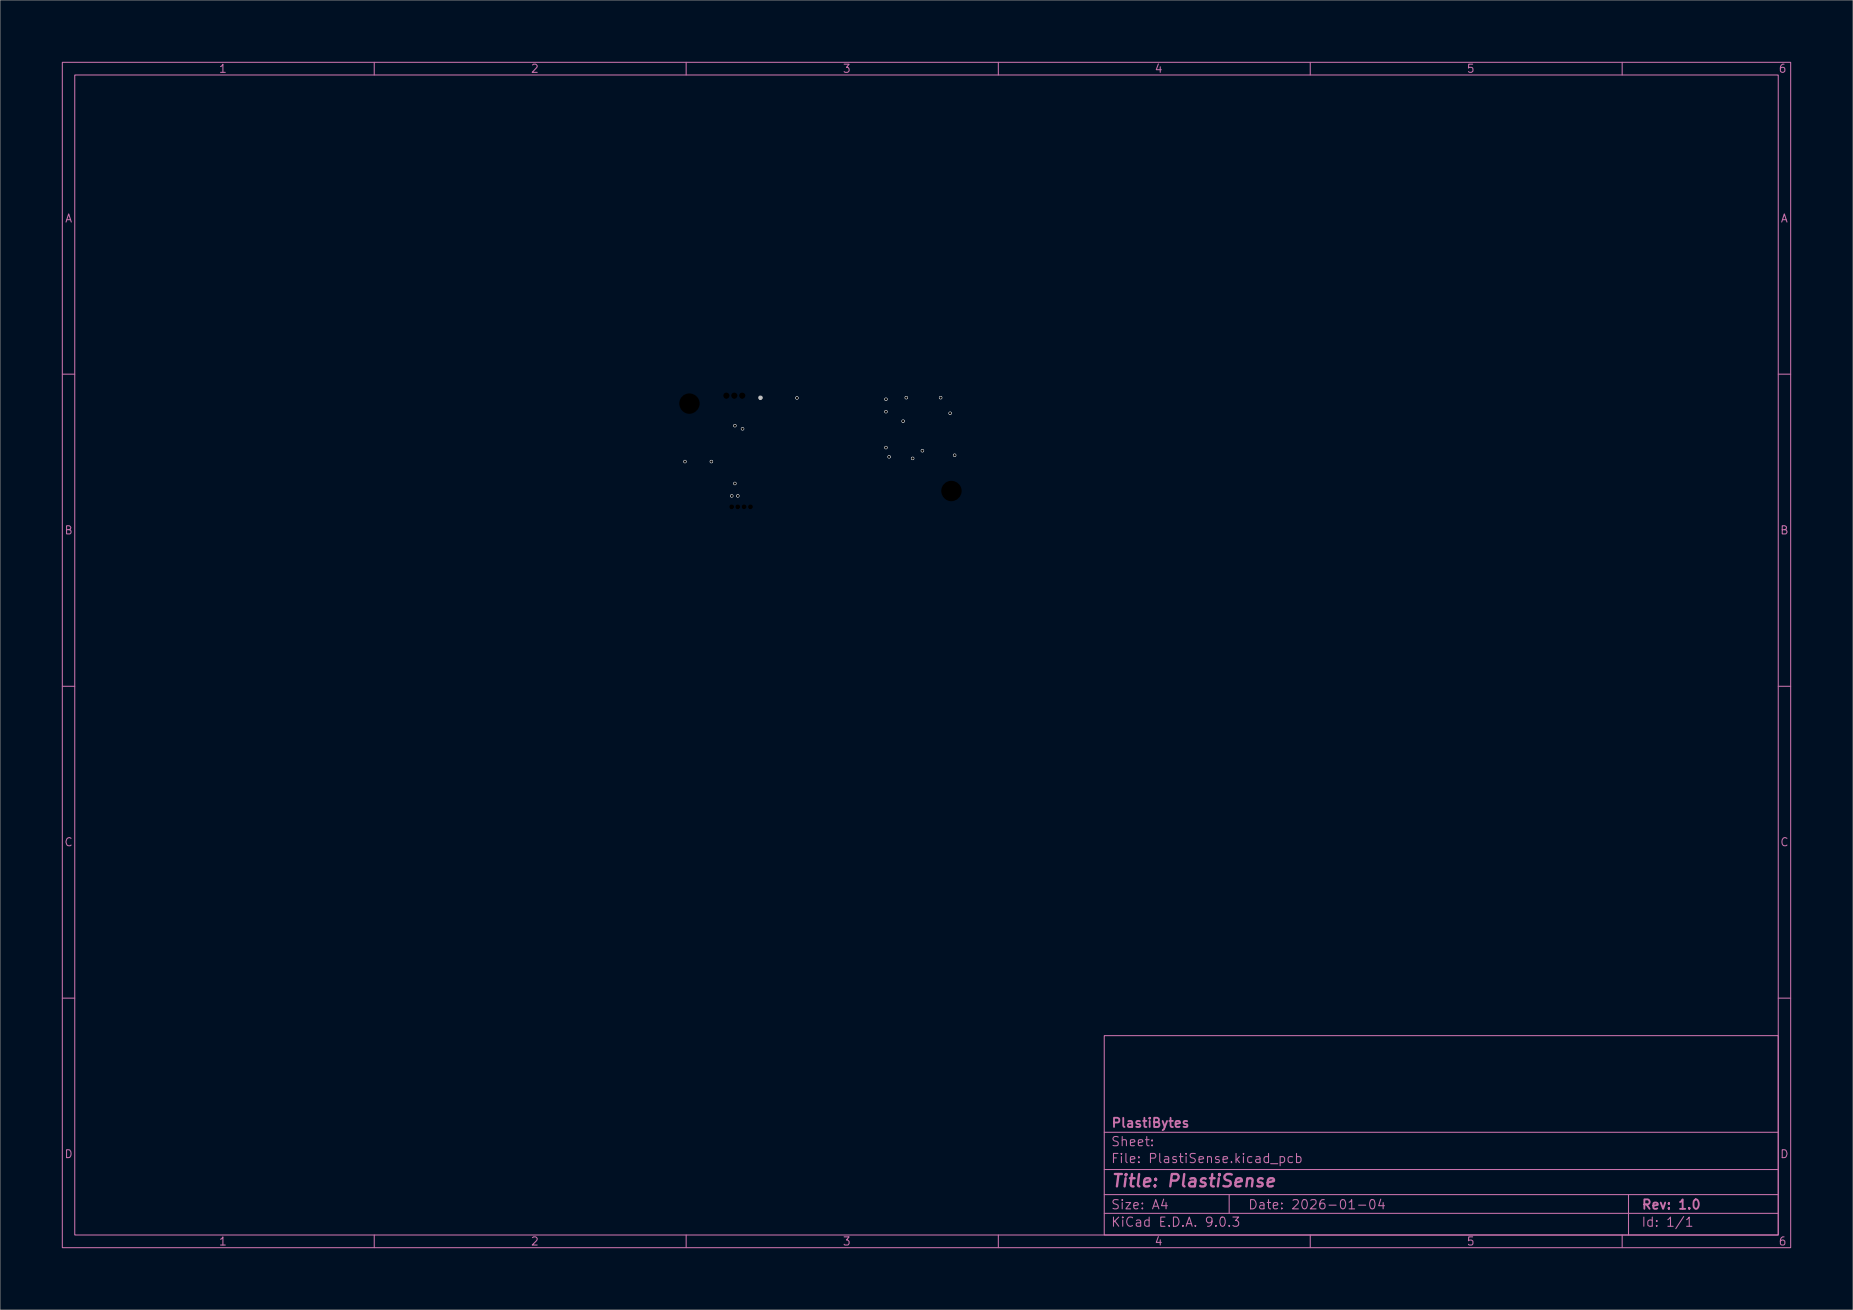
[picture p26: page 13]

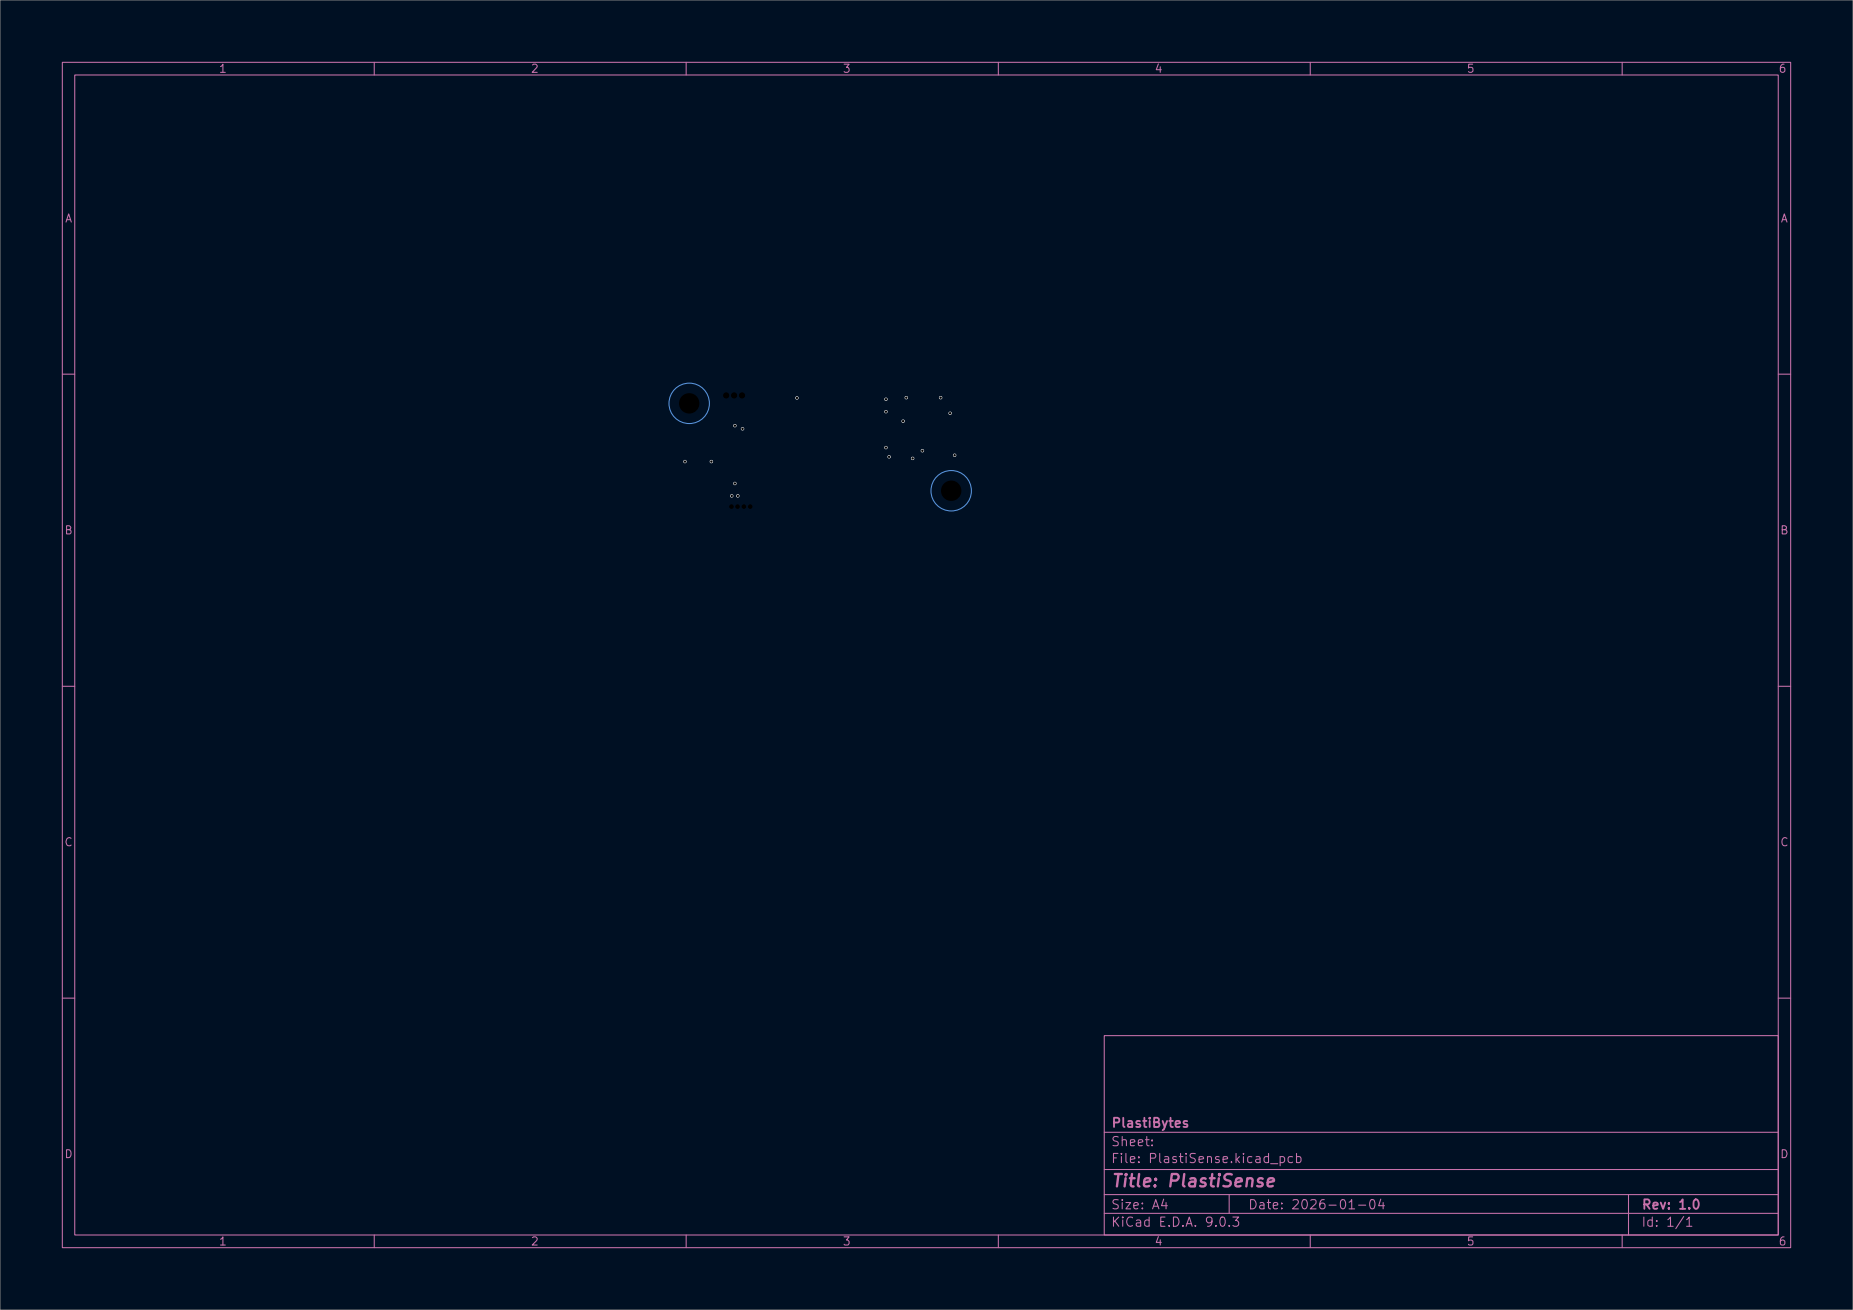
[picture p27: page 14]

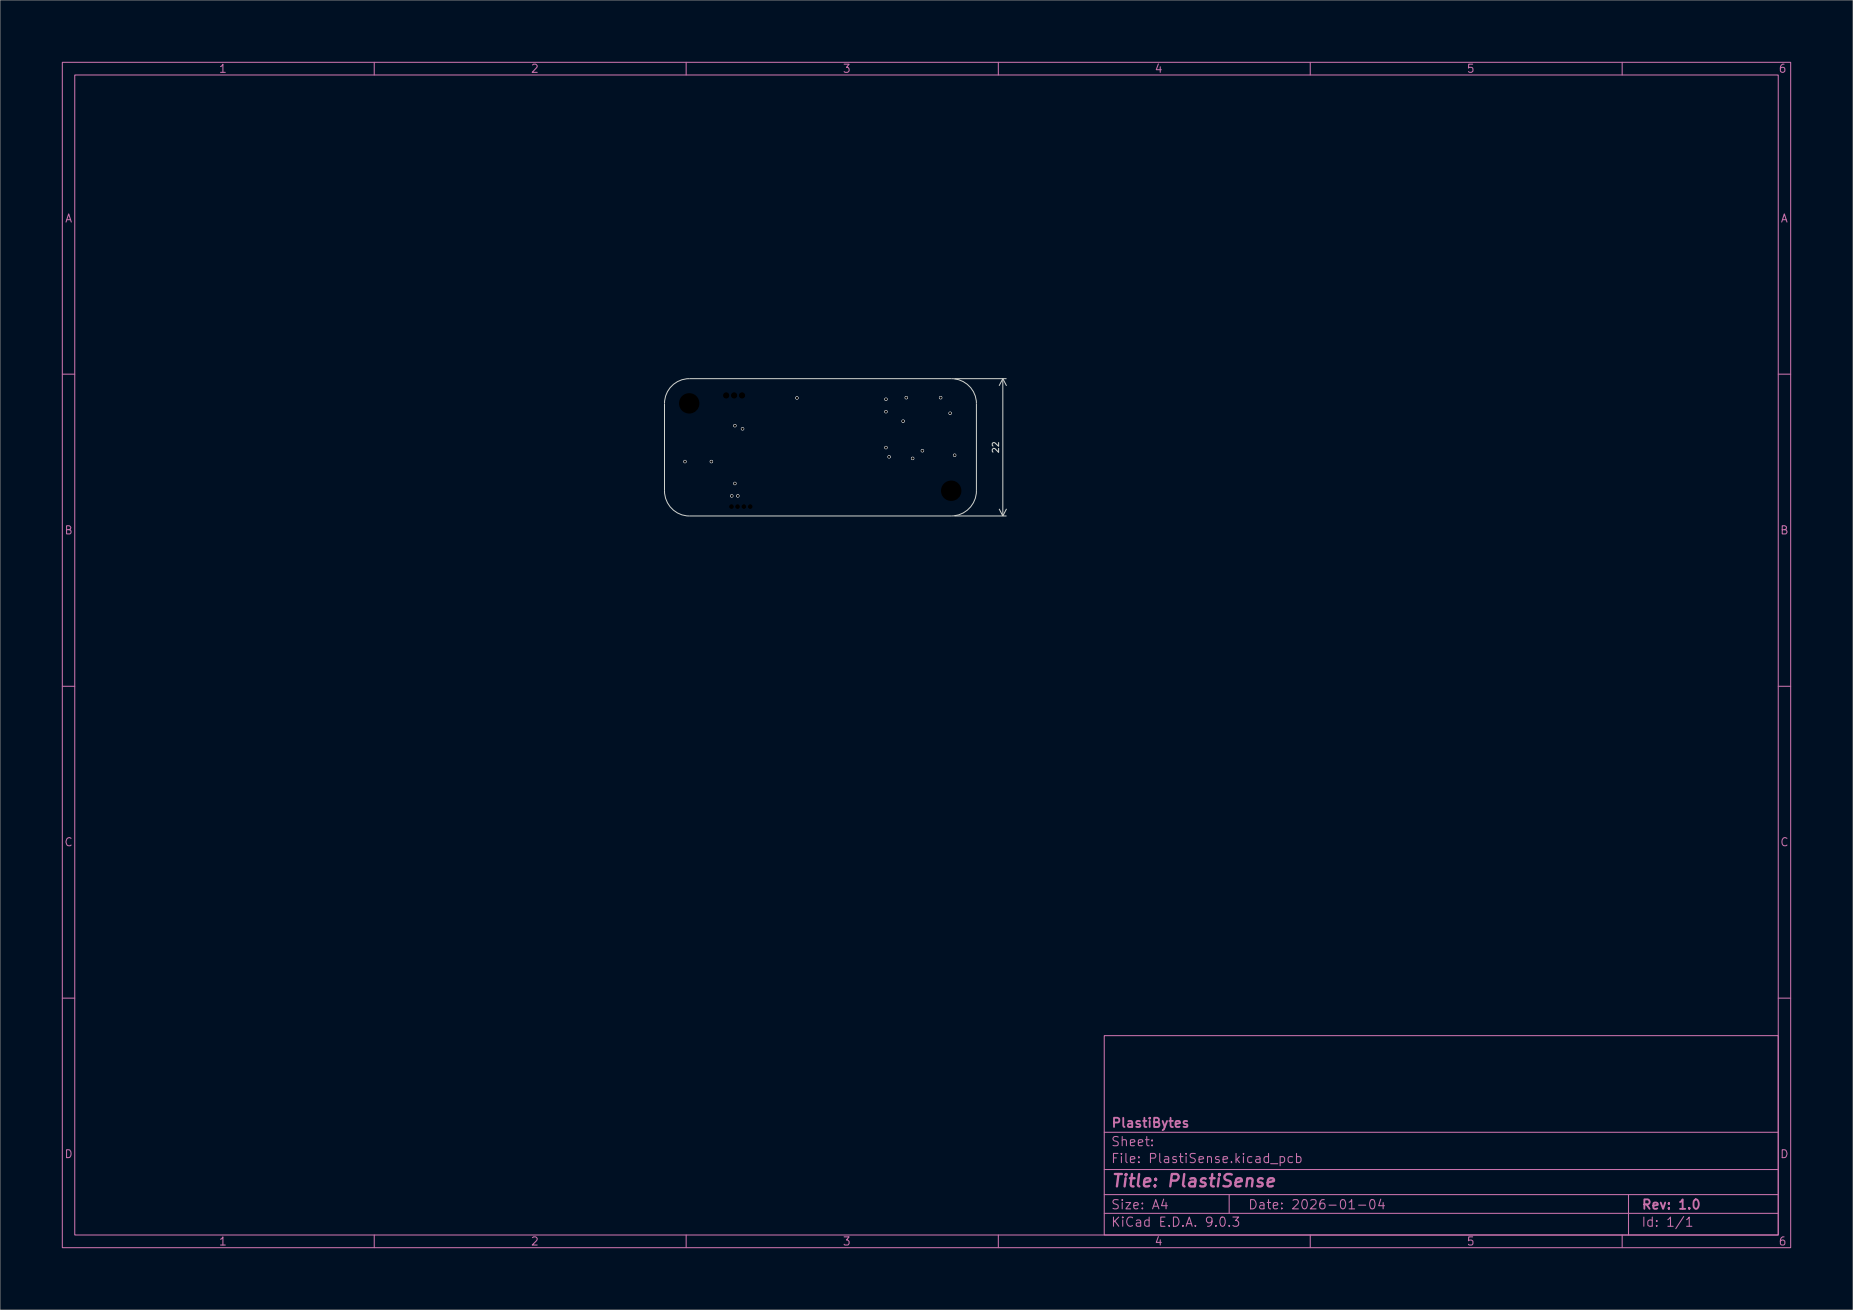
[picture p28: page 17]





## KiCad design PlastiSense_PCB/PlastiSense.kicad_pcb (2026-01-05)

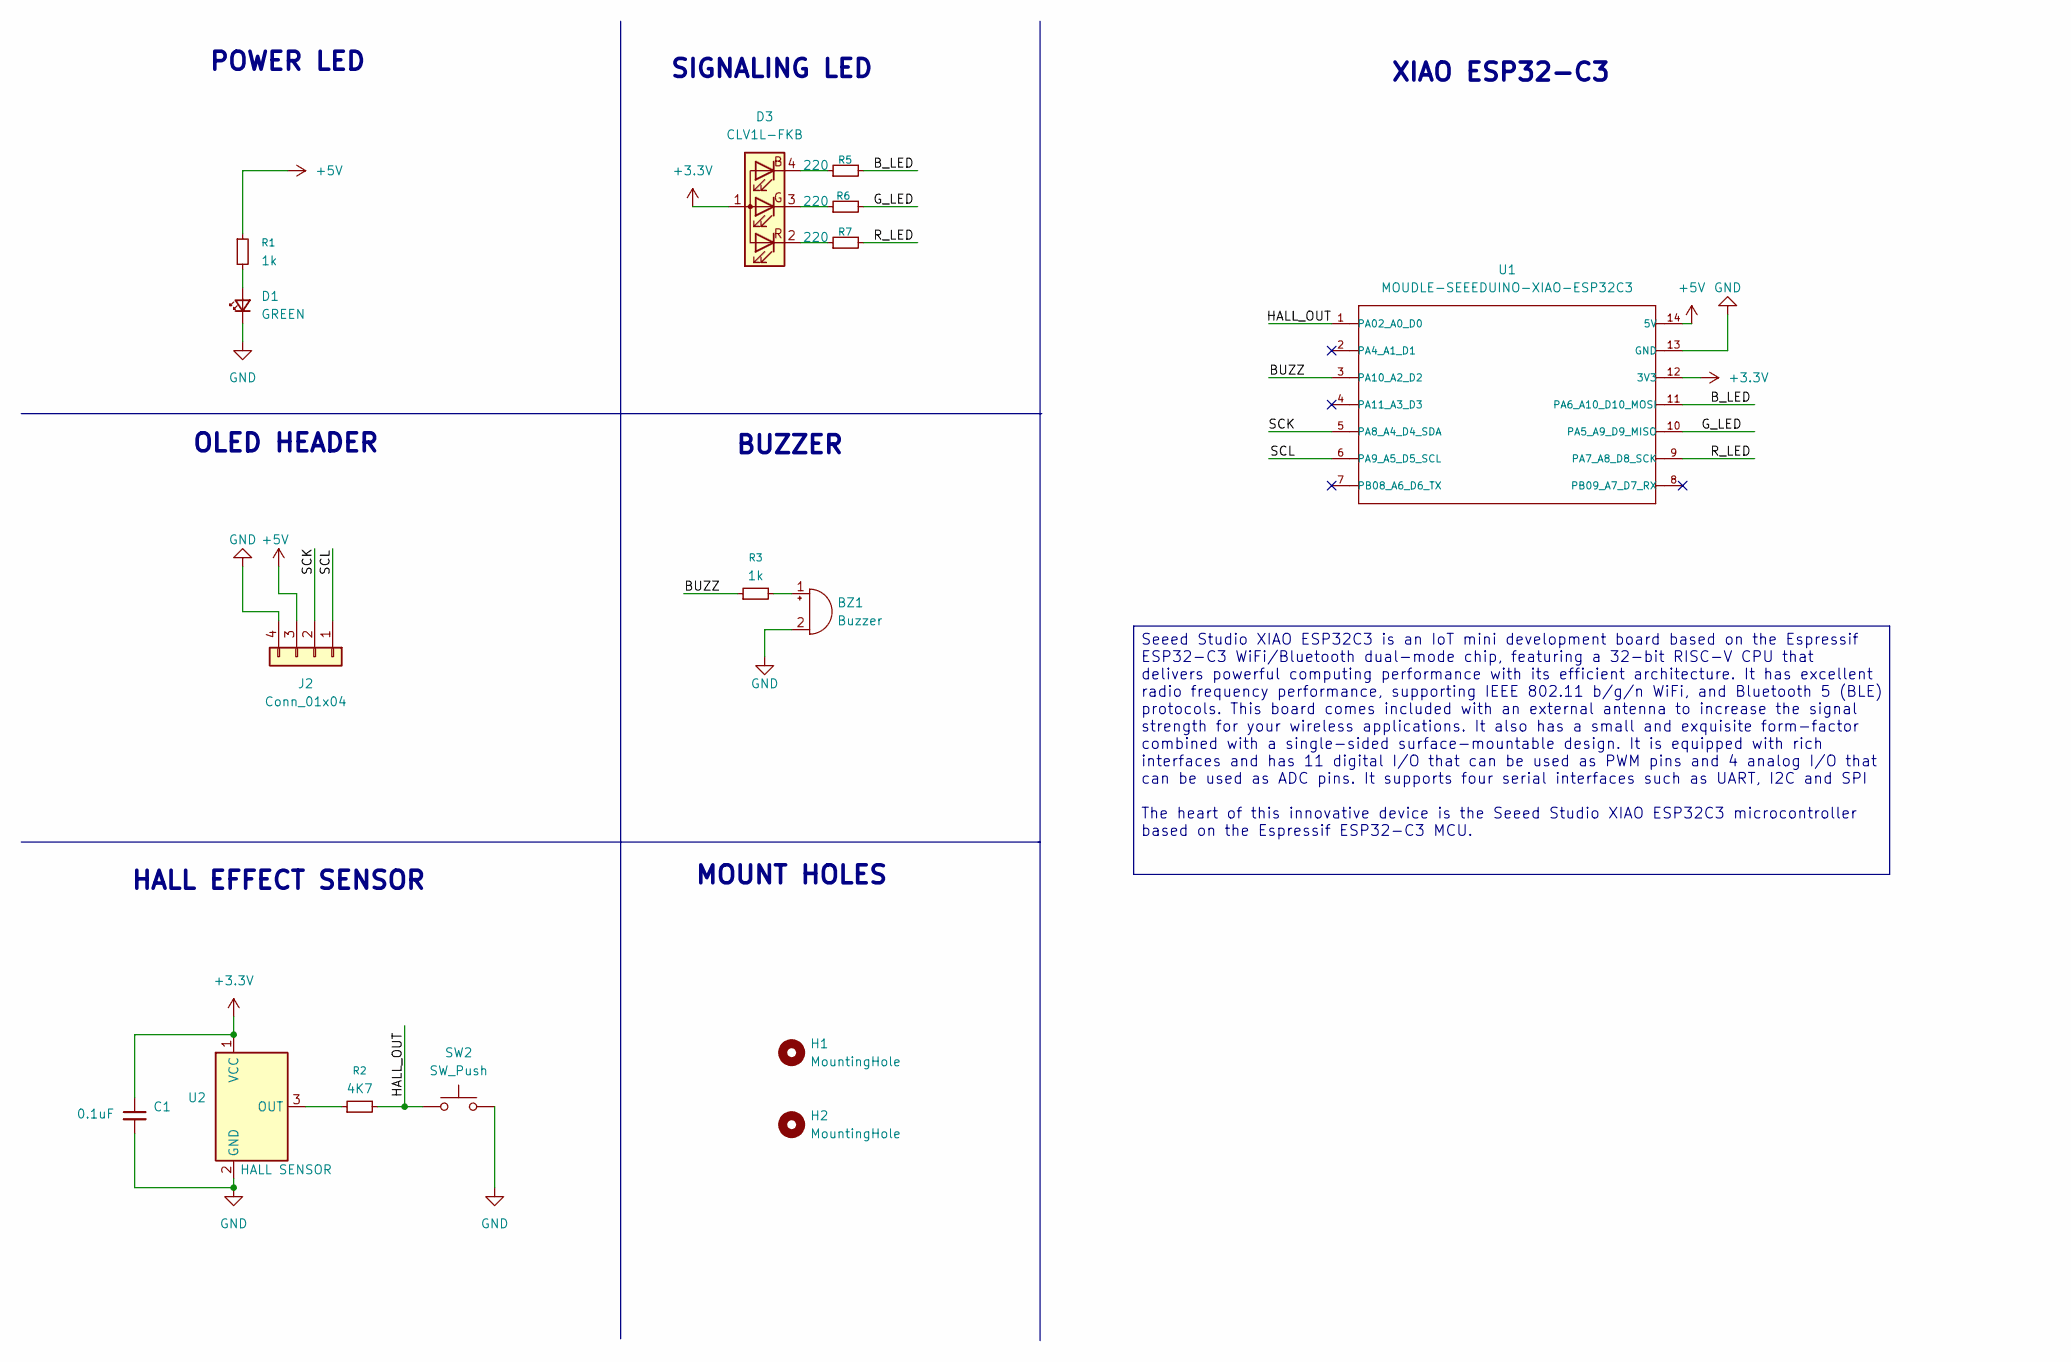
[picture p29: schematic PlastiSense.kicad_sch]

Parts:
BZ1: Buzzer; Buzzer_CUI_CPT-9019S-SMT
C1: 0.1uF; C_0504_1310Metric_Pad0.83x1.28mm_HandSolder
D1: GREEN; LED_0201_0603Metric_Pad0.64x0.40mm_HandSolder
D3: CLV1L-FKB; LED_Cree-PLCC4_3.2x2.8mm_CCW
H1, H2: MountingHole; MountingHole_3.2mm_M3
J2: Conn_01x04; PinHeader_1x04_P1.00mm_Vertical
R1, R3: 1k; R_0201_0603Metric_Pad0.64x0.40mm_HandSolder
R2: 4K7; R_0201_0603Metric_Pad0.64x0.40mm_HandSolder
R5, R6, R7: 220; R_0201_0603Metric_Pad0.64x0.40mm_HandSolder
SW2: SW_Push; SW_SPST_B3U-1000P
U1: MOUDLE-SEEEDUINO-XIAO-ESP32C3; MOUDLE14P-SMD-2.54-21X17.8MM
U2: HALL SENSOR; TO-92_Inline

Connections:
+3.3V: C1.1, D3.1 (A), U1.12 (3V3), U2.1 (VCC)
+5V: J2.3, R1.1, U1.14 (5V)
/BUZZ: R3.1, U1.3 (PA10_A2_D2)
/B_LED: R5.2, U1.11 (PA6_A10_D10_MOSI)
/G_LED: R6.2, U1.10 (PA5_A9_D9_MISO)
/HALL_OUT: R2.2, SW2.1, U1.1 (PA02_A0_D0)
/R_LED: R7.2, U1.9 (PA7_A8_D8_SCK)
/SCK: J2.2, U1.5 (PA8_A4_D4_SDA)
/SCL: J2.1, U1.6 (PA9_A5_D5_SCL)
GND: BZ1.2 (-), C1.2, D1.1 (K), J2.4, SW2.2, U1.13 (GND), U2.2 (GND)
unnamed: BZ1.1 (+), R3.2
unnamed: D1.2 (A), R1.2
unnamed: D3.4 (BK), R5.1
unnamed: D3.3 (GK), R6.1
unnamed: D3.2 (RK), R7.1
unnamed: R2.1, U2.3 (OUT)

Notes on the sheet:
MOUNT HOLES
HALL EFFECT SENSOR
OLED HEADER
BUZZER
SIGNALING LED
POWER LED
XIAO ESP32-C3
Seeed Studio XIAO ESP32C3 is an IoT mini development board based on the Espressif ESP32-C3 WiFi/Bluetooth dual-mode chip, featuring a 32-bit RISC-V CPU that delivers powerful computing performance with its efficient architecture. It has excellent radio frequency performance, supporting IEEE 802.11 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

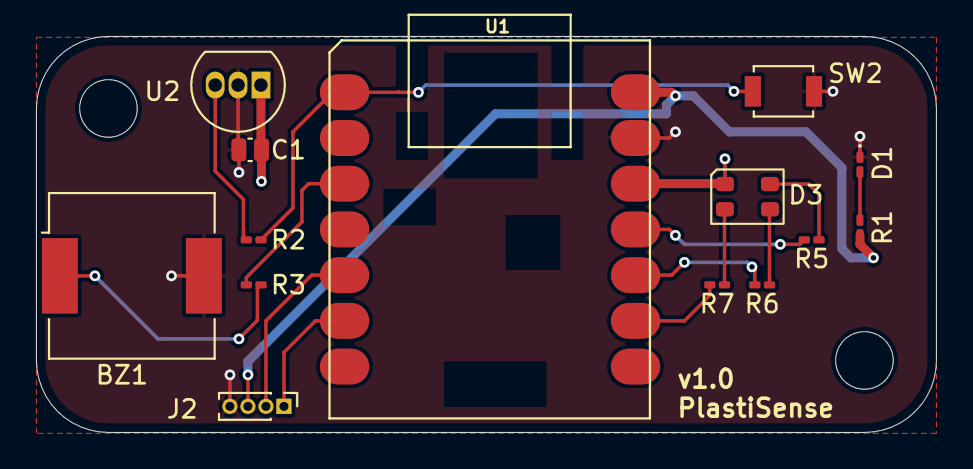
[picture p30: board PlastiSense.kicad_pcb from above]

Board: 4 copper layers, 50.0 x 22.0 mm, 16 parts (0 on the bottom side), 16 nets.

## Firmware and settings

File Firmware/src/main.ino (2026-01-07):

#include <ESPmDNS.h>
#include <EEPROM.h>
#include <WiFiManager.h>
#include <ArduinoOTA.h>
#include "WiFi.h"
#include "ESPAsyncWebServer.h"
#include "include/PersistSettings.h"
#include "config_winfidel.h"

bool bStatusLED = false;

#if CONFIG_ENABLE_WIFI
WiFiManager wifiManager;
AsyncWebServer server(80);
volatile int WiFi_status = WL_IDLE_STATUS;
const char mdnsName[] = MDNS_NAME;
const char wifiName[] = WIFI_HOSTNAME;
uint8_t dbgOTApercent = 100;
#endif //CONFIG_ENABLE_WIFI

#if CONFIG_PRINT_MEASUREMENTS_USB_CDC
int SerialInByte = 0;
bool bSerialPrintoutRequested = false;
#endif // CONFIG_PRINT_MEASUREMENTS_USB_CDC

void setup()
{
    pinMode(LED_RED_PIN, OUTPUT);
    digitalWrite(LED_RED_PIN, HIGH);
    pinMode(LED_GREEN_PIN, OUTPUT);
    digitalWrite(LED_GREEN_PIN, HIGH);
    pinMode(LED_BLUE_PIN, OUTPUT);
    digitalWrite(LED_BLUE_PIN, HIGH);

    LED_RED_ON();

    // Configure Serial communication
	Serial.begin(115200);   // USB-to-UART
    Serial0.begin(115200);  // TX/RX GPIOS

    Serial.println("Wireless Inline Filament Estimator, Low-Cost - WInFiDEL");
    Serial0.println("Wireless Inline Filament Estimator, Low-Cost - WInFiDEL");

#if CONFIG_ENABLE_WIFI
    WiFi.setHostname(wifiName);
#endif // CONFIG_ENABLE_WIFI

    delay(500);

    LED_GREEN_ON();

#if CONFIG_ENABLE_WIFI
    bool res;
    res = wifiManager.autoConnect("SK-WInFiDEL-Setup");

    if(!res) {
        Serial.println("Failed to connect or hit timeout");
        ESP.restart();
    }
    else {
        //if you get here you have connected to the WiFi
        Serial.println("Connected.");
    }

	Serial.print("WiFi IP: ");
	Serial.println(WiFi.localIP());

    if (!MDNS.begin(mdnsName))
    {
        Serial.println("Error starting mDNS");
    }
    else
    {
        Serial.println((String) "mDNS http://" + MDNS_NAME + ".local");
    }

    // Add service to MDNS-SD
    MDNS.addService("http", "tcp", 80);
#endif // CONFIG_ENABLE_WIFI

    EEPROM.begin(sizeof(calibration_t));
    calibration_init();

    adc_init();

#if CONFIG_ENABLE_WIFI
    Serial.print("Starting WebServer...");
	setupWebServer();
	server.begin();
    Serial.println("done.");

    Serial.print("WiFi IP: ");
    Serial.println(WiFi.localIP());

    /**
    * Enable OTA update
    */
    ArduinoOTA
    .onStart([]() {
      String type;
      if (ArduinoOTA.getCommand() == U_FLASH)
        type = "sketch";
      else // U_SPIFFS
        type = "filesystem";

      // NOTE: if updating SPIFFS this would be the place to unmount SPIFFS using SPIFFS.end()
      Serial.println("Start updating " + type);
    })
    .onEnd([]() {
      Serial.println("\nEnd");
    })
    .onProgress([](unsigned int progress, unsigned int total) {
        uint8_t percent = (progress / (total / 100));
        if (percent == dbgOTApercent)
        {
            return;
        }
        if ((percent%5) == 0)
        {
            Serial.printf("Progress: %u%%\r", percent);
            dbgOTApercent = percent;
        }
    })
    .onError([](ota_error_t error) {
      Serial.printf("Error[%u]: ", error);
      if (error == OTA_AUTH_ERROR) Serial.println("Auth Failed");
      else if (error == OTA_BEGIN_ERROR) Serial.println("Begin Failed");
      else if (error == OTA_CONNECT_ERROR) Serial.println("Connect Failed");
      else if (error == OTA_RECEIVE_ERROR) Serial.println("Receive Failed");
      else if (error == OTA_END_ERROR) Serial.println("End Failed");
    });
    ArduinoOTA.begin();
    Serial.println("Arduino OTA is on");
#endif // CONFIG_ENABLE_WIFI

    // Debug message to signal we are initialized and entering loop
	Serial.println("Ready to go.");

    i2c_scan_bus();
    LED_RED_OFF();

    Serial.println("Entering main loop");
    LED_RED_OFF();
    LED_GREEN_OFF();
    LED_BLUE_OFF();
}


void loop()
{
    Measurements_Tick();

#if CONFIG_ENABLE_WIFI
    ArduinoOTA.handle();
#endif // CONFIG_ENABLE_WIFI

#ifdef CONFIG_PRINT_MEASUREMENTS_USB_CDC
    int available = Serial.available();
    if(available > 0)
    {
        SerialInByte = Serial.read();
        if(SerialInByte == 'S' || SerialInByte == 's')
        {
            bSerialPrintoutRequested = true;
        }
        else if(SerialInByte == 'E' || SerialInByte == 'e')
        {
            bSerialPrintoutRequested = false;
            LED_SERIAL_OFF();
        }
    }
#endif // CONFIG_PRINT_MEASUREMENTS_USB_CDC
}

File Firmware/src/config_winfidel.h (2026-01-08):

#ifndef __WINFIDEL_CFG__
#define __WINFIDEL_CFG__

#define MDNS_NAME "winfidel"
#define WIFI_HOSTNAME "WInFiDEL by SK"

#ifndef CONFIG_PRINT_MEASUREMENTS_USB_CDC
#define CONFIG_PRINT_MEASUREMENTS_USB_CDC                                      \
  1    // Set to `1` if we want serial (USB-to-Serial) printout for every
       // measurement.
#endif // CONFIG_PRINT_MEASUREMENTS_USB_CDC

#ifndef CONFIG_PRINT_MEASUREMENTS_UART_GPIO
#define CONFIG_PRINT_MEASUREMENTS_UART_GPIO                                    \
  1    // Set to `1` if we want serial (TX GPIO) printout for every measurement.
#endif // CONFIG_PRINT_MEASUREMENTS_UART_GPIO

#ifndef CONFIG_ENABLE_WIFI
#define CONFIG_ENABLE_WIFI                                                     \
  1 // Set to `1` if we want to use WiFi (ie not requred for Serial only
    // application)
#endif

#define CALIBRATION_POINT_SAMPLE_COUNT                                         \
  32 // Number of ADC samples to take for new calibration point
#define CALIBRATION_POINT_ACCURACY_POINT                                       \
  50 // We expect all CALIBRATION_POINT_SAMPLE_COUNT samples to be
     // within CALIBRATION_POINT_ACCURACY_POINT of each other
     // in order to have successful calibration point creation

#define CALIBRATION_BOUNDARY_ITEMS                                             \
  2 // We need lower and upper boundary item for safety
#define MAX_CALIBRATION_POINTS (10 + CALIBRATION_BOUNDARY_ITEMS)
#define ADC_MIN 0 // Minimum value we can get from our ADC (should be always 0)
#define ADC_MIN_EQUALS_MM                                                      \
  5.0f // ADC_MIN should be considered this diameter (in mm)
#define ADC_MAX                                                                \
  4095 // Maximum value we can get from our ADC (should be 2^n-bits)
#define ADC_MAX_EQUALS_MM                                                      \
  0.0f // ADC_MAX should be considered this diameter (in mm)

#define CAL_POINT_EMPTY {.adc = ADC_MIN, .mm = ADC_MIN_EQUALS_MM}
#define CAL_POINT_FIRST {.adc = ADC_MIN, .mm = ADC_MIN_EQUALS_MM}
#define CAL_POINT_LAST {.adc = ADC_MAX, .mm = ADC_MAX_EQUALS_MM}

#define ADC_MAX_SAMPLES                                                        \
  64 // Maximum number of ADC samples we can take in one measurement cycle
#define ADC_SAMPLES_PER_MEASUREMENT_CYCLE                                      \
  16 // How many samples to take for each measurement cycle
#define ADC_FINAL_ADC_VALUE_USING_MEAN // Use mean instead of average ADC value

// #define ADC_CHIP_IS_MCP3221 // Specify which ADC chip we are using
// #define ADC_CHIP_MCP3021                            // Specify which ADC chip
// we are using
#define ADC_CHIP_INTERNAL // Use internal ADC

#ifdef ADC_CHIP_INTERNAL
#define ADC_PIN A0
#endif

#define ADC_I2C_ADDRESS 0x4D // 7-bit I2C address of our ADC IC
#define I2C_SCL_PIN SCL      // SCL pin number (GPIO 7 on XIAO ESP32C3)
#define I2C_SDA_PIN SDA      // SDA pin number (GPIO 6 on XIAO ESP32C3)

#define LED_RED_PIN 9   // RED LED pin number
#define LED_GREEN_PIN 10 // GREEN LED pin number
#define LED_BLUE_PIN 8  // BLUE LED pin number
#define LED_MEASUREMENT_PIN LED_GREEN_PIN
#define LED_SERIAL_PIN LED_BLUE_PIN
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
